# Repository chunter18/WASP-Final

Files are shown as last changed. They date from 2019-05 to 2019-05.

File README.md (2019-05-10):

# WASP

This is the final code submission of my senior design project for Santa Clara University School of Engineering. 

Team memebers:
Tyler Hack
Cole Hunter
Daniel Webber

Advisers:
Dr. Wilson
Dr. Dezfouli

## What is WASP?

WASP (Wireless Analog Sensor Platform) is my teams senior deisng project, the goal of which is to create a simple, powerful, accurate, and compact way to measure accleration for sattelite tests. Here are some snippets from our abstract:

WASP’s goal is to augment and eventually replace the bulky, costly, and inefficient data acquisition systems used for vibrational reliability tests on satellites. This will enable precise testing of conditions on a smaller time frame and at a lower cost.

The project objective is to design a low power, small footprint, wireless sensor module designed to be the next generation in space flight operational testing. Currently, Space and Aerospace companies conduct non-destructive vibrational experiments on their vehicles to ensure that they will survive the high G-forces required to leave the atmosphere. These tests are conducted with over 200 wired accelerometers simultaneously connected to multi-thousand dollar data acquisition modules. These systems result in a disarray of wired connections making installing and debugging these sensors an excessively laborious and time-consuming process. We propose a low-cost, battery-powered module, designed for engineers, to augment and eventually replace the current testing and data acquisition system. The goal is to maintain the accuracy and precision of the current standard of testing, but eliminate the pitfalls of a wired system. These experiments typically last for tens of minutes and up to an hour each time, during which the module will be collecting vibrational data at a very high speed and streaming this data continuously to a base station for analysis. The module must be ultra-low-powered as sensor placement in hard to access locations can occur weeks before the actual experiment takes place. The module will need to be small enough so as not to contribute to system load, which can skew measurements. The final system needs to function in parity with the current system.

As of June 2019, we submitted our final design for a board (including 5 assembled and evaluated boards funded by our project sponsor - Analog Devices) as well as all of the code for the main application we wrote.

In this repository you will find our teams final platform code, the board files, instructions for evaluating one of the rev1 WASP modules, and anything else we want to deliver as a part of the project. To see some more (messy) test code, you can have a look at my other WASP repo, where you can see the expiriments we ran throughout the year.  

## Evaluation Instuctions

For these instructions, we will assume you are famiair with the WICED (Wireless Internet Connectivity for Embedded Devices) software. If you arent, please head over to https://www.cypress.com/products/wiced-software and download WICED studio. We are using version 6.2 for all of our WASP builds, but any version ^ or greater should work.

To start, clone this repository and place it into your WICED studio directory. On windows, the default directory is Documents\WICED-Studio-6.2\43xxx_Wi-Fi\apps. 

Next, we need to modify a few of the base WICED files.
1. First we need to modify wwd_wifi. WASP adds a function to dissasociate with the wifi network to make changing the netowork dynamically easy - the file is otherwise unchanged, so replacing the files wont break any other builds. To do this, replace the wwd_wifi.c in WICED-Studio-6.2\43xxx_Wi-Fi\WICED\WWD\internal\ with the file in the cloned wwd folder, and replace the wwd_wifi.h file in WICED-Studio-6.2\43xxx_Wi-Fi\WICED\WWD\include\ folder.
2. Navigate to https://community.cypress.com/docs/DOC-16139 and follow the steps in the attached document to add the quicksilver platform to the OTA2 libraries. NOTE: it is not necessary to edit the Quicksilver platform.c/.h files for our use case. Hopefully in future versions of WICED these changes will be merged into WICED, so if you notice thats the case you can safely ignore this step. 
3. We will also need to modiy the SPI bitbang code to support MOSI idle high for the ADX4008 ADC. Replace 43xxx_Wi-Fi\WICED\platform\MCU\BCM4390x\peripherals\platform_spi_i2c.c with the one from the repo. 
4. For the final edit, we will need to edit the OpenOCD file for the CYW so that we can use the SEGGER J-link as our JTAG programmer. Replace BCM4390x.cfg with the one from this repo in 43xxx_Wi-Fi\tools\OpenOCD. 

To use the SEGGER J-link as your JTAG programmer, you will also need to follow the instructions at https://community.cypress.com/community/wiced-wifi/wiced-wifi-forums/blog/2018/03/19/downloading-and-debugging-cyw43907-using-jlink-segger. NOTE: this link does not include any instructions to install the j-link drivers - please do this as well.

Next, we need to build the OTA2 extract application that WASPs OTA system relies on. To do so, simple place this make target into your makefiles pane `snip.ota2_extract-Quicksilver_EVL` and double click to build it. This app doesnt need to be downloaded, but it is a prerequsite to building the main app.

Our final step before building is to change some of the WASP defualts to better match your test case.
1. Change the battery capacity in headers/WASP_i2c.h to match your battery of choice. Many popular battery sizes are included, so you may just comment out all but the correct one. NOTE: WASP expects a single celled LiPo battery.
2. Change the server IP address to match you own in headers/wasp_network_global.h
3. Change the wifi networking in wifi_config_dct.c to match your own.

You are no finally ready to build the WASP app! To do so, place the following make target into your list `WASP.wasp_main-Quicksilver_EVL JTAG=jlink ota2_image download_apps download run` and run it. This will build and download the app onto the WASP board for evaluation.

IMPORTANT!!! The wasp server uses the clients MAC address to correlate which data came from which board. By default, WICE will build all the board images with the same mac adress - you will need to change the mac for each board you upload to by editing the `generated_mac_address.txt` file.

To see what the platform is running, connect any UART to USB device to the WASP board UART headers, and open the associated com port. the WASP app prints some various information to the console, which can be useful for debugging.

In addition to this, the WASP server will need to be running in order to see the full functionality of the test app (otherwise the board will stop after failing to connect over TCP). To build the server, cd into the server directory of the repo and run make. The server will then be ready to run 

troubleshooting
1. Check that the OTA extract was built successfully
2. Check that the built server IP matches the actual IP of the server on the local network. 
3. Did the OTA failsafe accidently get set?
3. Feel free to contact me for any other issues you may face. 

## Server

To run the server, first build the file using the included makefile, and run the generated file `wasp`. Note: the wasp server relies on many of the libraries provided by the linux kernel, so make sure the file is built on a semi-recent linux machine.

When the server starts, you should see it immidetly start printing out some basic information, like the servers current mode, the number of reciever threads running, and a table of connected boards which will initially be empty. 

Fundamentally, the server has three different modes: Hibernate (0), Initializing Test Sequence (1), and Test Active (2). The mode is set by a file which will be generated for you by the server. The default mode is hibernate, which will send any connected boards back to hibernate. Each board that connects will have its mac address displayed on the table, as well as its self test status and the time since its last registration with the server.

ONce you have turned on your boards and have seen thier connections on the table, you can begin to test 

## Evaluating the OTA functionality

To use the OTA function of the WASP board, you will need to follow a few additional steps.

1. First, you will need to build your new application to be loaded. To do so, simply add ota2_image to your makefile while removing any of the download commands like so: `WASP.wasp_main-Quicksilver_EVL ota2_image`. This will build the the file `OTA2_image_file.bin` in the build/WASP.wasp_main-Quicksilver_EVL/ directory. This file includes all of the pieces necessary for the full app in a single file (bootloader, filesystem, apps code, dct, etc)
2. Place the included mongoose HTTP server and OTA image file together in the same directory on the server and run the mongoose server.
3. Make sure the OTA flag is set by the TCP portion of the server - TODO
4. Watch it update! you may wish to connect to the WASP board via UART to watch the download progress. The log level has been set to it max allowed level so the UART will be printing a lot of data. You should see the download complete, the board restart, extract the new file, and finllay run the newly updated application.

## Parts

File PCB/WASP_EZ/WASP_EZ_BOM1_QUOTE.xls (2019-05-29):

This is a sample BOM for Sierra Circuits' online BOM pricing system. Please use this preferred format for your BOM that you upload.
Note: DNI applies to whole row. If only some specific locations of a given ITEM are not to be installed, please create two rows for that item and mark one as DNI.
BOM: WASPEZ_1
Assembly Part Number/Revision: 1
Customer / Company Name: Daniel Webber
Item # | Quantity per board | Manufacturer Part # | Do Not Install | Reference designators | Vendor (optional) | Vendor Part Number (optional) | Value (optional) | Size / Footprint (optional) | Part description/ specs (optional, but recommended) | Manfacturer (optional)
1 | 1 | TPS63020DSJR |  | U1 | Mouser | 595-TPS63020DSJR |  | VSON-14 | Switching Voltage Regulators 93% Eff Buck-Boost Converter | TI
2 | 1 | LTC2941CDCB-1#TRMPBF |  | U2 | Mouser | LTC2941CDCB-1#TRMPBF |  | DFN-6 | Battery Management 1A I2C Bat Gas Gauge w/ Int Sense Res | Analog Devices
3 | 2 | CRCW040210R0JNEDC |  | R15, R17 | Mouser | 71-CRCW040210R0JNEDC | 10 ohms | R0402 | 10R 5% 0402 (1005 Metric) SMD | Vishay
4 | 2 | CRCW040220K0JNED |  | R6, R45 | Mouser | 71-CRCW0402J-20K-E3 | 20k ohms | R0402 | 20K 5% 0402 (1005 Metric) SMD | Vishay
5 | 2 | RC0402JR-0733KL |  | R21, R22 | Mouser | 603-RC0402JR-0733KL | 33k ohms | R0402 | 33K 5% 0402(1005) | Yageo
6 | 4 | RC0402JR-0747KL |  | R3, R4, R12, R13 | Mouser | 603-RC0402JR-0747KL | 47k ohms | R0402 | 47K 5% 0402(1005) | Yageo
7 | 6 | RC0402JR-13100KL |  | R5, R10, R11, R16, R24, R26 | Mouser | 603-RC0402JR-13100KL | 100k ohms | R0402 | 100K 5% 0402(1005) | Yageo
8 | 2 | RT0402FRE07130RL |  | R23, R25 | Mouser | 603-RT0402FRE07130RL | 130 ohms | R0402 | 130R 0.063W 5% 0402 (1005 Metric) SMD | Yageo
9 | 1 | RC0402FR-07143KL |  | R2 | Mouser | 603-RC0402FR-07143KL | 143k ohms | R0402 | 143K 1% 0402(1005) | Yageo
10 | 1 | RC0402FR-07715RL |  | R9 | Mouser | 603-RC0402FR-07715RL | 715 ohms | R0402 | 715R 0.063W 1% 0402 (1005 Metric) SMD | Yageo
11 | 1 | RC0402FR-07910KL |  | R1 | Mouser | 603-RC0402FR-07910KL | 910k ohm | R0402 | 910K 0.063W 1% 0402 (1005 Metric) SMD | Yageo
12 | 1 | AD4008BCPZ-RL7 |  | U6 | Mouser | 584-AD4008BCPZ-RL7 |  | LFCSP-10 | Analog to Digital Converters - ADC 16-Bit, 500 KSPS PulSAR ADC | Analog Devices
13 | 1 | ADXL1004BCPZ |  | U4 | Mouser | 584-ADXL1004BCPZ |  | LFCSP-32 | Accelerometers Low Noise 50kHz 500g 1-axis accel | Analog Devices
14 | 7 | CRCW04020000Z0EDC |  | R7, R8, R18, R19, R28, R35, R38 | Mouser | 71-CRCW04020000Z0EDC | 0 ohm | R0402 | Jumper 0402 (1005 Metric) | Yageo
15 | 1 | APG1608CGKC/T |  | DS1 | Mouser | 604-APG1608CGKC/T |  | LED 0603 | LED, SMT, 0603(1608), 0.25mm Thickness, Green | Kingbright
16 | 1 | S2B-PH-K-S(LF)(SN) |  | P2 | Digikey | 455-1719-ND |  |  | Male Header, Pitch 2 mm, 1 x 2 Position, Height 4.8 mm, Tail Length 3.4 mm, | JST Sales America Inc.
17 | 1 | LT1461CIS8-3.3#PBF |  | U5 | Digikey | LT1461CIS8-3.3#PBF-ND |  | 8-SOIC | Series Voltage Reference IC ±0.08% 100mA 8-SOIC | Analog Devices
18 | 1 | QUICKSILVER |  | M1 | Arrow | QUICKSILVER |  |  | Module, Antenna, .05 pitch, https://www.arrow.com/en/products/quicksilver/arrow-development-tools | Arrow
19 | 2 | RCWE0603R220FKEA |  | R14, R20 | Mouser | 71-RCWE0603R220FKEA | .22 ohm | R0603 | Current Sense Resistors - SMD 1/5watt .22ohms 1% 100ppm | Vishay
20 | 1 | XFL4020-102MEC |  | L1 | Mouser | 994-XFL4020-102MEC |  |  | Shielded Power Inductor, 1 uH, 64 MHz | Coilcraft
21 | 1 | TPS73733DCQR |  | U3 | Mouser | 595-TPS73733DCQR | 3.3V LDO | SOT-223 | LDO Voltage Regulators Cap-Free 1A LDO Reg | TI
22 | 1 | TPS780180300DRVR |  | U9 | Mouser | 595-TPS780180300DRVR | 1.8V LDO | WSON-6 | Single Output LDO, 150 mA, Fixed 1.8, 3.0 V Output, 2.2 to 5.5 V Input, | TI
23 | 1 | SIS407ADN-T1-GE3 |  | Q1 | Mouser | 78-SIS407ADN-T1-GE3 |  | PowerPAK 1212-8 | MOSFET -20V Vds 8V Vgs PowerPAK 1212-8 | Vishay
24 | 1 | NTUD3170NZT5G |  | Q2 | Mouser | 863-NTUD3170NZT5G |  | SOT-963-6 | Small Signal MOSFET, 20 V, 220 mA, Dual N-Channel, 6-Pin SOT-963, Pb-Free, Tape and Reel | ON Semiconductor
25 | 2 | 5012 |  | TP3, TP13 | Mouser | 534-5012 |  |  | Circuit Board Hardware - PCB WHITE TEST POINT | Keystone
26 | 1 | APG1608SURKC/T |  | DS2 | Mouser | 604-APG1608SURKC/T | RED LED | LED 0603 | Standard LEDs - SMD Red, Water Clear 320mcd, 631nm | Kingbright
27 | 2 | B3U-1000P |  | SW1, SW2 | Mouser | 653-B3U-1000P |  |  | Tactile Switches Top Actuated w/o boss w/o ground | Omron
28 | 1 | INA219BIDCNT |  | U7 | Digikey | 296-27898-2-ND |  | SOT-23-8 | Current Monitor Regulator High-Side 10mA SOT-23-8 | TI
29 | 4 | 77311-801-04LF |  | P1, P3, P4, P5 | Digikey | 649-77311-801-04LF |  |  | Headers & Wire Housings Unshrd Hdr, Sngl Rw Thru-Mount,4P,Strght | Amphenol FCI
30 | 2 | EMK105BJ105KV-F |  | C14, C31 | Digikey | 587-2477-1-ND | 1uF | C0402 | CAP CER 1UF 16V X5R 0402 | Taiyo Yuden
31 | 3 | CC0402KPX5R6BB225 |  | C36, C37, C22 | Mouser | 603-CC0402KPX56BB225 | 2.2uF | C0402 | Multilayer Ceramic Capacitors MLCC - SMD/SMT 2.2uF 10% 10V | Yageo
32 | 12 | GRM188R61A106KE69D |  | C1, C2, C5, C6, C7, C8, C9, C16, C19, C20, C21,C10 | Digikey | 490-10474-1-ND | 10uF | C0603 | CAP CER 10UF 10V X5R 0603 | Murata
33 | 8 | CGA2B2X5R1A104K050BA |  | C3, C15, C17, C18, C28, C29, C35, C4 | Digikey | 445-12156-1-ND | 0.1uF | C0402 | CAP CER 0.1UF 10V X5R 0402 | TDK
34 | 4 | CC0603KRX5R9BB104 |  | C11, C23, C26, C27 | Digikey | 311-4046-1-ND | 0.1uF | C0603 | CAP CER 0.1UF 50V X5R 0603 | Yageo
35 | 2 | GRM155R71C104KA88J |  | C24, C25 | Digikey | 490-6328-1-ND | 0.1uF | C0402 | CAP CER 0.1UF 16V X7R 0402 | Murata
36 | 1 | C0603X103F5JAC7867 |  | C12 | Digikey | 399-13405-1-ND | 10000PF | C0603 | CAP CER 10000PF 50V U2J 0603 | KEMET
END OF BOM

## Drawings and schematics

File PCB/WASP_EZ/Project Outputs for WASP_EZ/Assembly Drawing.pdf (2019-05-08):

Line # 123456789 | C3, C15, C17, C18, C28, C29, C35 | CAP 100nF 6.3V 0402(1005)

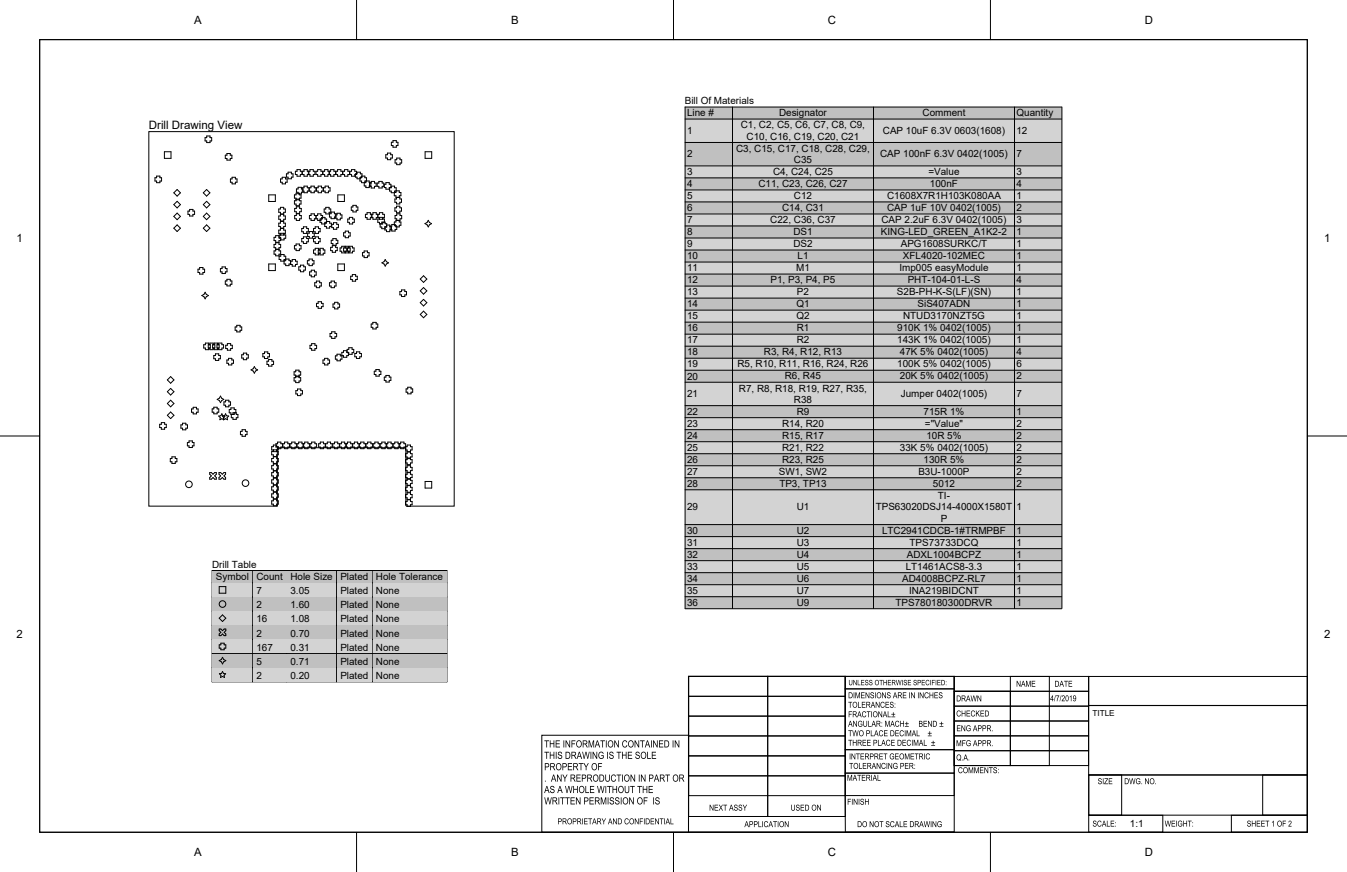
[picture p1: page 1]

Designator | Comment | Quantity

12 | P1, P3, P4, P5 | PHT-104-01-L-S | 1273412311114111114627122222211111111

C1, C2, C5, C6, C7, C8, C9, C10, C16, C19, C20, C21 | CAP 10uF 6.3V 0603(1608)

C4, C24, C25 | =Value
C11, C23, C26, C27 | 100nF

C12 | C1608X7R1H103K080AA
C14, C31 | CAP 1uF 10V 0402(1005)
C22, C36, C37 | CAP 2.2uF 6.3V 0402(1005)
DS1 | KING-LED_GREEN_A1K2-2
DS2 | APG1608SURKC/T

10 | L1 | XFL4020-102MEC
11 | M1 | Imp005 easyModule

13 | P2 | S2B-PH-K-S(LF)(SN)
14 | Q1 | SiS407ADN
15 | Q2 | NTUD3170NZT5G
16 | R1 | 910K 1% 0402(1005)
17 | R2 | 143K 1% 0402(1005)
18 | R3, R4, R12, R13 | 47K 5% 0402(1005)
19 | R5, R10, R11, R16, R24, R26 | 100K 5% 0402(1005)
20 | R6, R45 | 20K 5% 0402(1005)
21 | R7, R8, R18, R19, R27, R35, R38 | Jumper 0402(1005)

22 | R9 | 715R 1%
23 | R14, R20 | ="Value"
24 | R15, R17 | 10R 5%
25 | R21, R22 | 33K 5% 0402(1005)
26 | R23, R25 | 130R 5%
27 | SW1, SW2 | B3U-1000P
28 | TP3, TP13 | 5012
29 | U1 | TI-TPS63020DSJ14-4000X1580T P

30 | U2 | LTC2941CDCB-1#TRMPBF
31 | U3 | TPS73733DCQ
32 | U4 | ADXL1004BCPZ
33 | U5 | LT1461ACS8-3.3

162 | 1.08 | Plated | None
167 52 | 0.71 | Plated | None

0.70 | Plated | None
0.31 | Plated | None

0.20 | Plated | None

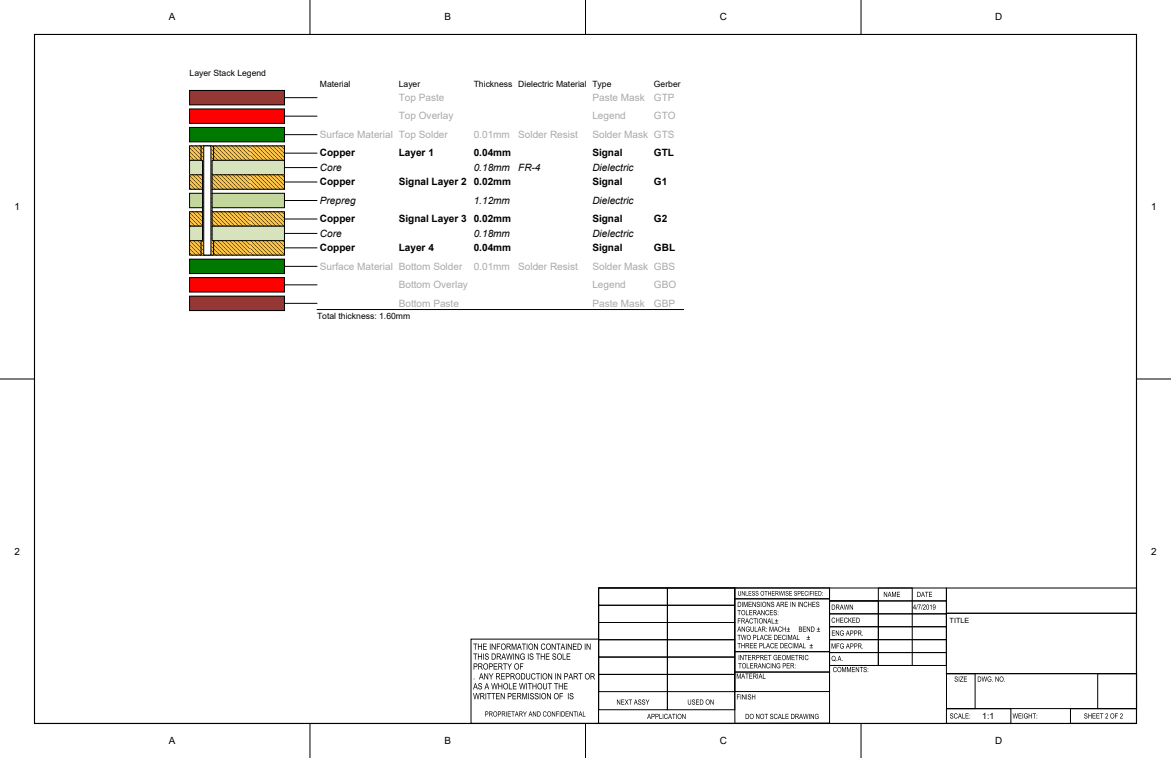
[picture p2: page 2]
Material; Layer; Thickness Dielectric Material Type; Gerber; Top Paste; Paste Mask GTP; Top Overlay; Legend; GTO; Surface Material Top Solder; 0.01mm Solder Resist; Solder Mask GTS; Copper; Layer 1; Signal; GTL; Core; Dielectric; Signal Layer 2 0.02mm; Prepreg; Signal Layer 3 0.02mm; Layer 4; GBL; Surface Material Bottom Solder 0.01mm Solder Resist; Solder Mask GBS; Bottom Overlay; GBO; Bottom Paste; Paste Mask GBP; Total thickness: 1.60mm; TITLE

Layer Stack Legend

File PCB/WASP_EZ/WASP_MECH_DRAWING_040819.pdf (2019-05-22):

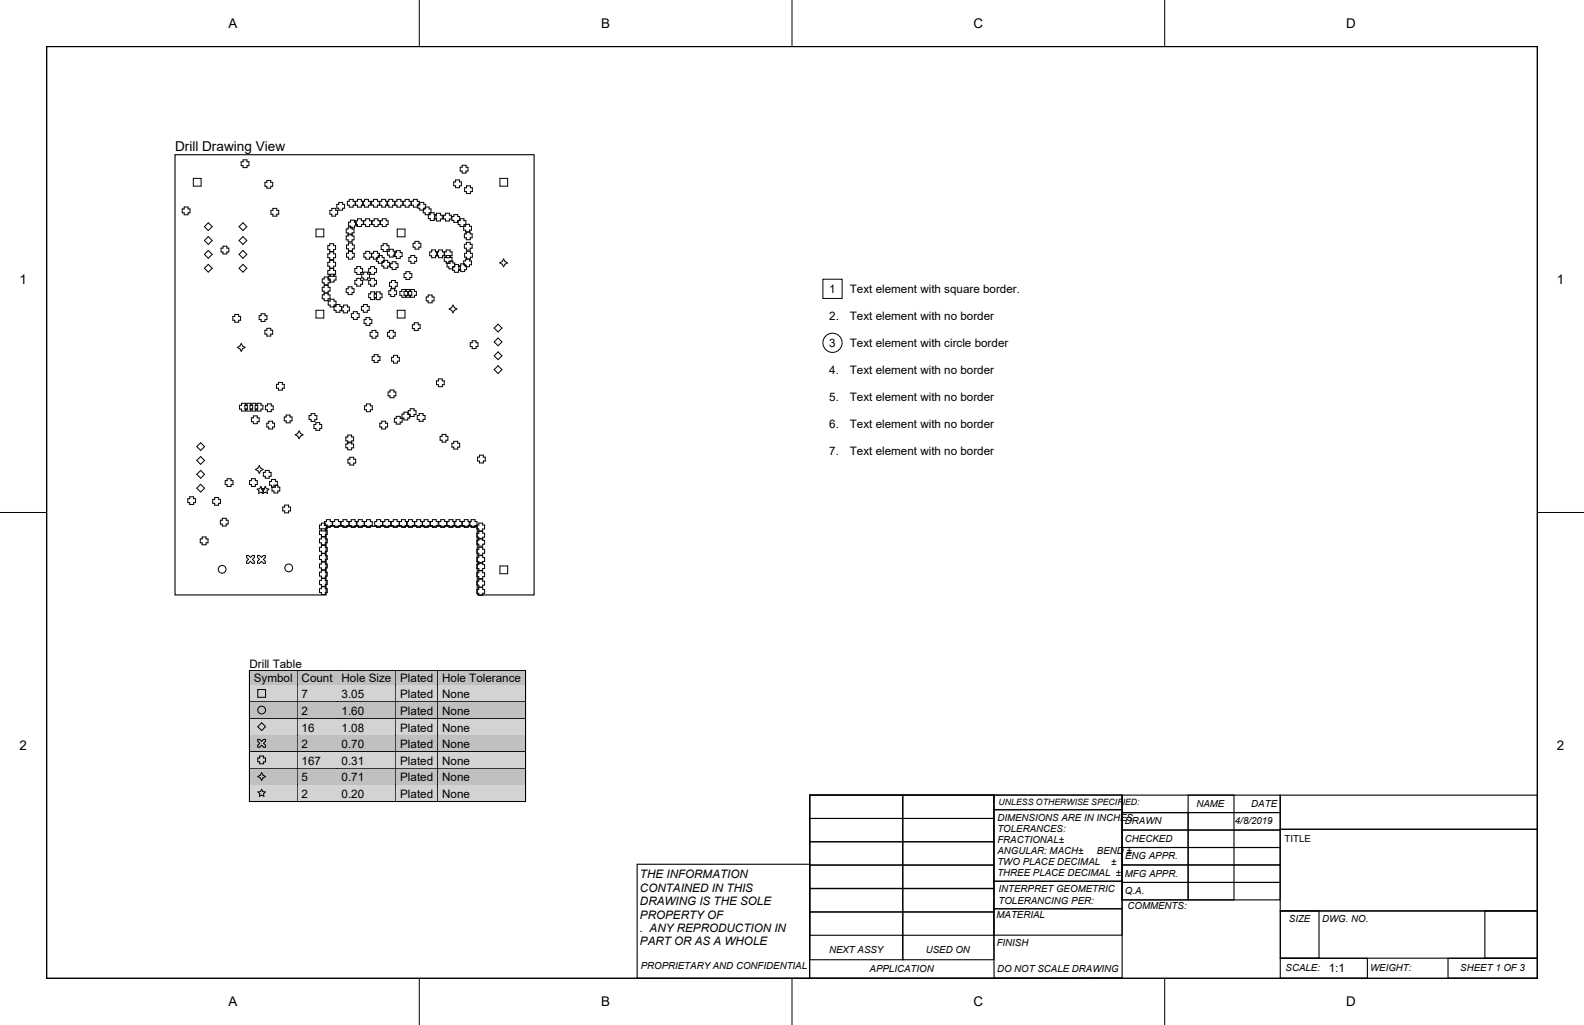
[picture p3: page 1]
Drill Table; DWG. NO.; COMMENTS:; FINISH; APPLICATION; DO NOT SCALE DRAWING; NEXT ASSY; USED ON; ANGULAR: MACH±; BEND ±; NAME; DATE; TITLE; MFG APPR.; ENG APPR.; CHECKED; DRAWN; SCALE:; WEIGHT:; SHEET 1 OF 3; SIZE

Drill Drawing View

1 Text element with square border.

2. Text element with no border

3 Text element with circle border

4. Text element with no border

5. Text element with no border

6. Text element with no border

7. Text element with no border

Symbol | Count | Hole Size | Plated | Hole Tolerance

7 | 3.05 | Plated | None
2 | 1.60 | Plated | None
16 | 1.08 | Plated | None
2 | 0.70 | Plated | None
167 | 0.31 | Plated | None
5 | 0.71 | Plated | None
2 | 0.20 | Plated | None

UNLESS OTHERWISE SPECIFIED:
DIMENSIONS ARE IN INCHES
TOLERANCES:
FRACTIONAL±
TWO PLACE DECIMAL ±
THREE PLACE DECIMAL ±
INTERPRET GEOMETRIC
TOLERANCING PER:
MATERIAL

THE INFORMATION
CONTAINED IN THIS
DRAWING IS THE SOLE
PROPERTY OF
. ANY REPRODUCTION IN
PART OR AS A WHOLE

PROPRIETARY AND CONFIDENTIAL

1 | 1
2 | 2
Material | Layer | Thickness Dielectric Material Type | Gerber
Top Paste | Paste Mask GTP
| Top Overlay | | Legend | GTO
Surface Material Top Solder | 0.01mm Solder Resist | Solder Mask GTS
Copper | Layer 1 | 0.04mm | Signal | GTL
Core | | 0.18mm FR-4 | Dielectric
Copper | Signal Layer 2 | 0.02mm | Signal | G1
Prepreg | | 1.12mm | Dielectric
Copper | Signal Layer 3 | 0.02mm | Signal | G2
Core | | 0.18mm | Dielectric
Copper | Layer 4 | 0.04mm | Signal | GBL
Surface Material Bottom Solder 0.01mm Solder Resist | Solder Mask GBS
| Bottom Overlay | | Legend | GBO
Bottom Paste | Paste Mask GBP
Total thickness: 1.60mm

Layer Stack Legend

DWG. NO.

4/8/2019

COMMENTS:
MATERIAL

UNLESS OTHERWISE SPECIFIED:

INTERPRET GEOMETRIC
TOLERANCING PER:

DIMENSIONS ARE IN INCHES
TOLERANCES:
FRACTIONAL±
ANGULAR: MACH± BEND ±
TWO PLACE DECIMAL ±
THREE PLACE DECIMAL ±

NAME DATE

TITLE

Q.A.

MFG APPR.

ENG APPR.

CHECKED

DRAWN

THE INFORMATION
CONTAINED IN THIS
DRAWING IS THE SOLE
PROPERTY OF
. ANY REPRODUCTION IN

SIZE

# C26 C27C²³

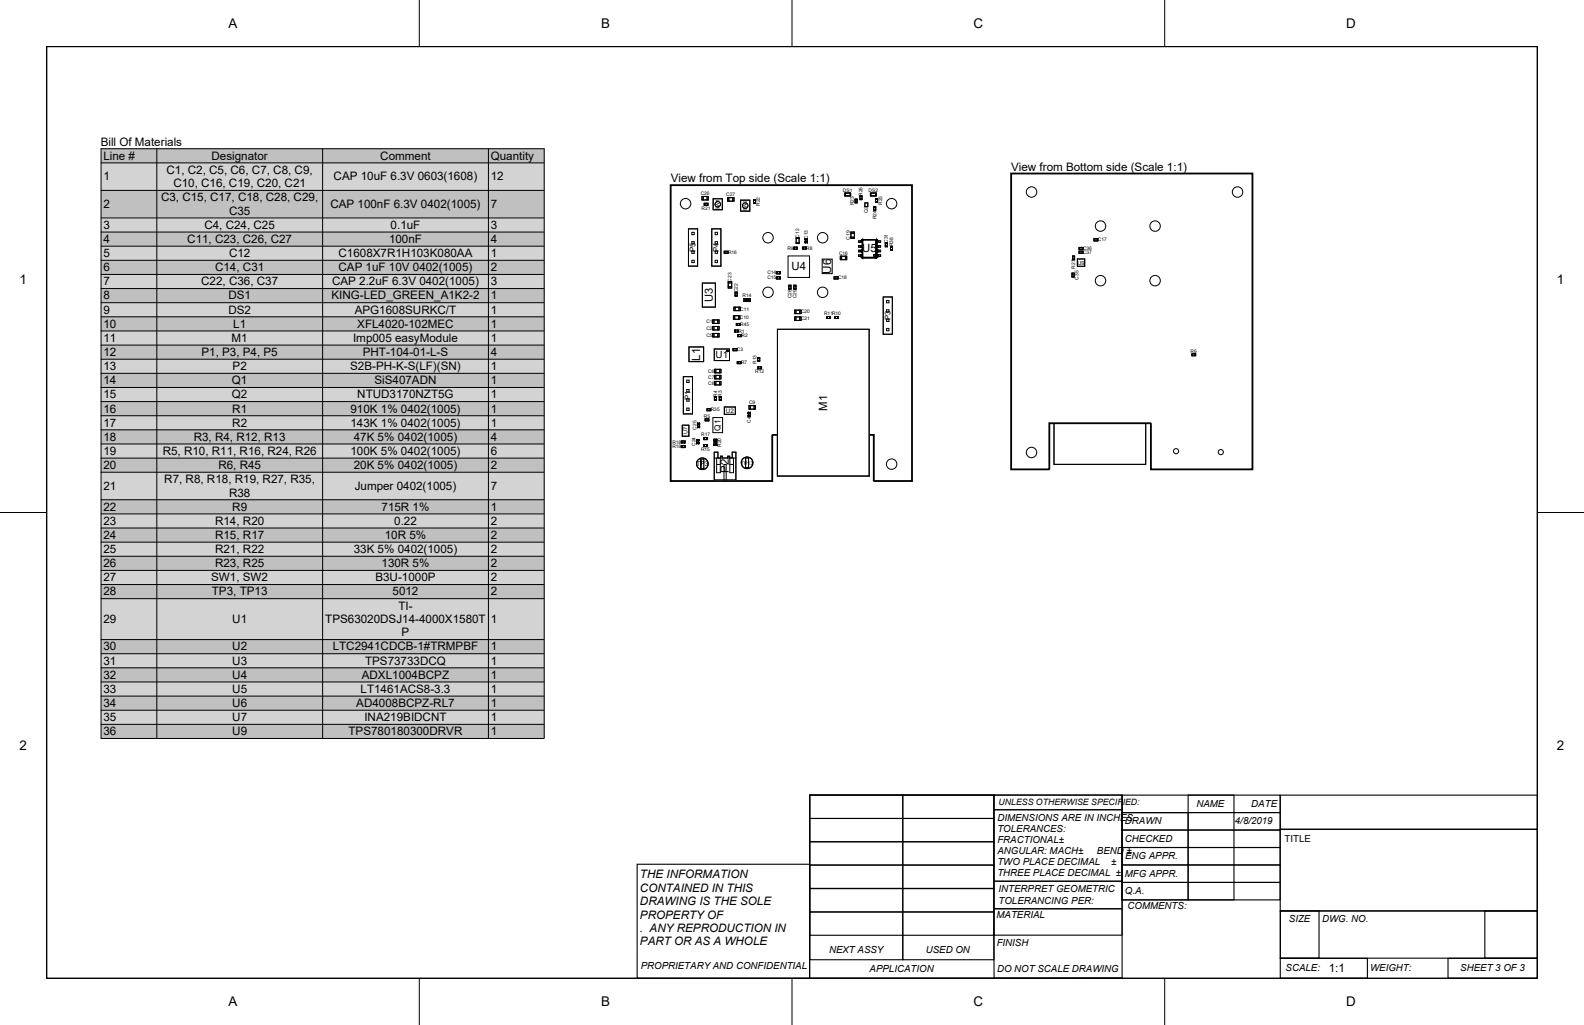
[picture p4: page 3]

Line # | Designator | Comment | Quantity
1 | C1, C2, C5, C6, C7, C8, C9, C10, C16, C19, C20, C21 | CAP 10uF 6.3V 0603(1608) | 12

View from Bottom side (Scale 1:1)

View from Top side (Scale 1:1)

2 | C3, C15, C17, C18, C28, C29, C35 | CAP 100nF 6.3V 0402(1005) | 7

3 | C4, C24, C25 | 0.1uF | 3
4 | C11, C23, C26, C27 | 100nF | 4
5 | C12 | C1608X7R1H103K080AA | 1
6 | C14, C31 | CAP 1uF 10V 0402(1005) | 2
7 | C22, C36, C37 | CAP 2.2uF 6.3V 0402(1005) | 3
8 | DS1 | KING-LED_GREEN_A1K2-2 | 1
9 | DS2 | APG1608SURKC/T | 1
10 | L1 | XFL4020-102MEC | 1
11 | M1 | Imp005 easyModule | 1
12 | P1, P3, P4, P5 | PHT-104-01-L-S | 4
13 | P2 | S2B-PH-K-S(LF)(SN) | 1

14 | Q1 | SiS407ADN | 1
15 | Q2 | NTUD3170NZT5G | 1
16 | R1 | 910K 1% 0402(1005) | 1
17 | R2 | 143K 1% 0402(1005) | 1
18 | R3, R4, R12, R13 | 47K 5% 0402(1005) | 4
19 | R5, R10, R11, R16, R24, R26 | 100K 5% 0402(1005) | 6
20 | R6, R45 | 20K 5% 0402(1005) | 2
21 | R7, R8, R18, R19, R27, R35, R38 | Jumper 0402(1005) | 7

22 | R9 | 715R 1% | 1
23 | R14, R20 | 0.22 | 2
24 | R15, R17 | 10R 5% | 2
25 | R21, R22 | 33K 5% 0402(1005) | 2
26 | R23, R25 | 130R 5% | 2
27 | SW1, SW2 | B3U-1000P | 2
28 | TP3, TP13 | 5012 | 2
29 | U1 | TI-TPS63020DSJ14-4000X1580T P | 1

30 | U2 | LTC2941CDCB-1#TRMPBF | 1
31 | U3 | TPS73733DCQ | 1
32 | U4 | ADXL1004BCPZ | 1
33 | U5 | LT1461ACS8-3.3 | 1
34 | U6 | AD4008BCPZ-RL7 | 1
35 | U7 | INA219BIDCNT | 1
36 | U9 | TPS780180300DRVR | 1

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

THE INFORMATION
CONTAINED IN THIS
DRAWING IS THE SOLE
PROPERTY OF
. ANY REPRODUCTION IN

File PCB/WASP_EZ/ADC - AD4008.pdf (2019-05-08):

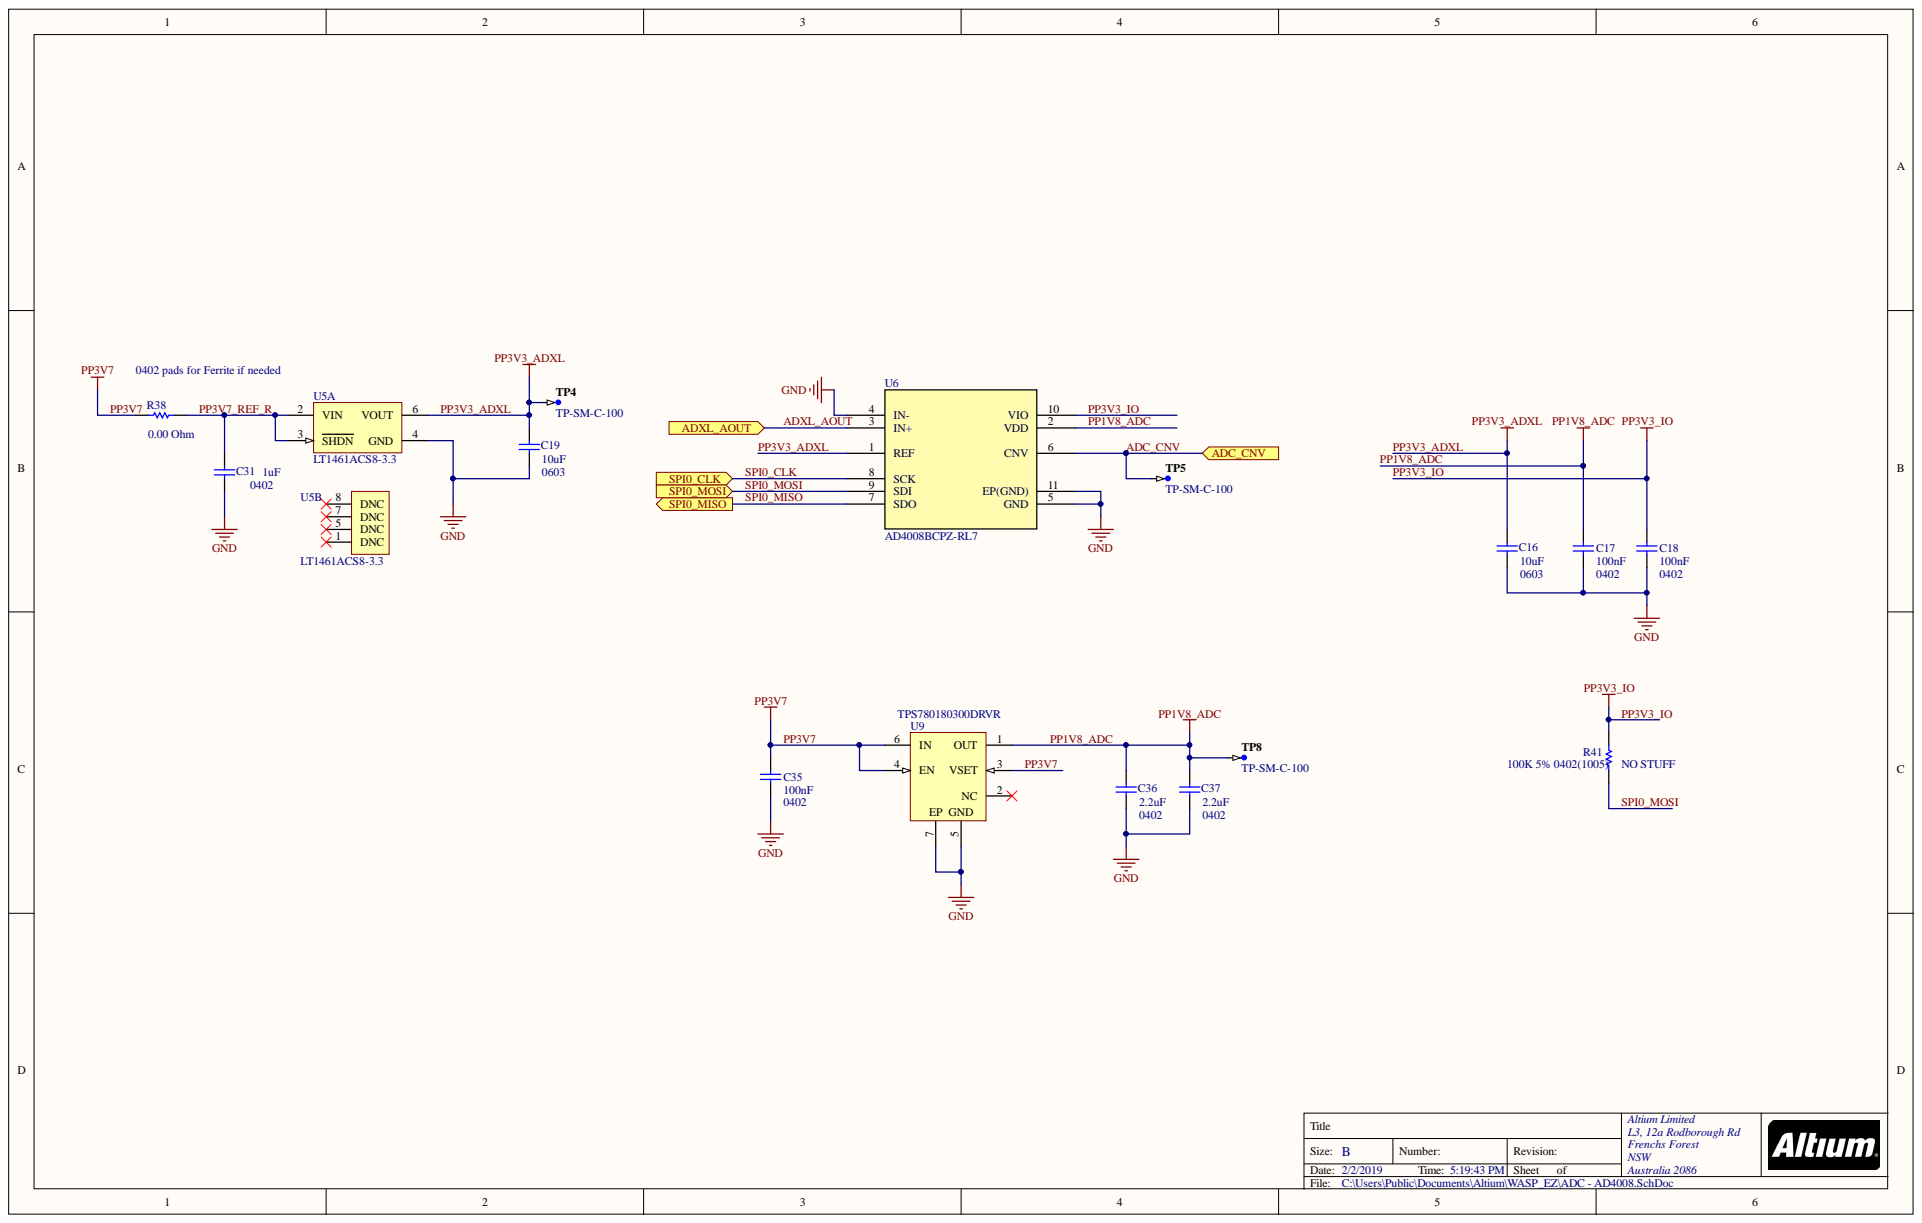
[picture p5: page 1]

0402 pads for Ferrite if needed

Title | Altium Limited L3, 12a Rodborough Rd Frenchs Forest NSW Australia 2086

Size: B | Number: | Revision:
Date: 2/2/2019 Time: 5:19:43 PM | | Sheet of
File: C:\Users\Public\Documents\Altium\WASP_EZ\ADC - AD4008.SchDoc

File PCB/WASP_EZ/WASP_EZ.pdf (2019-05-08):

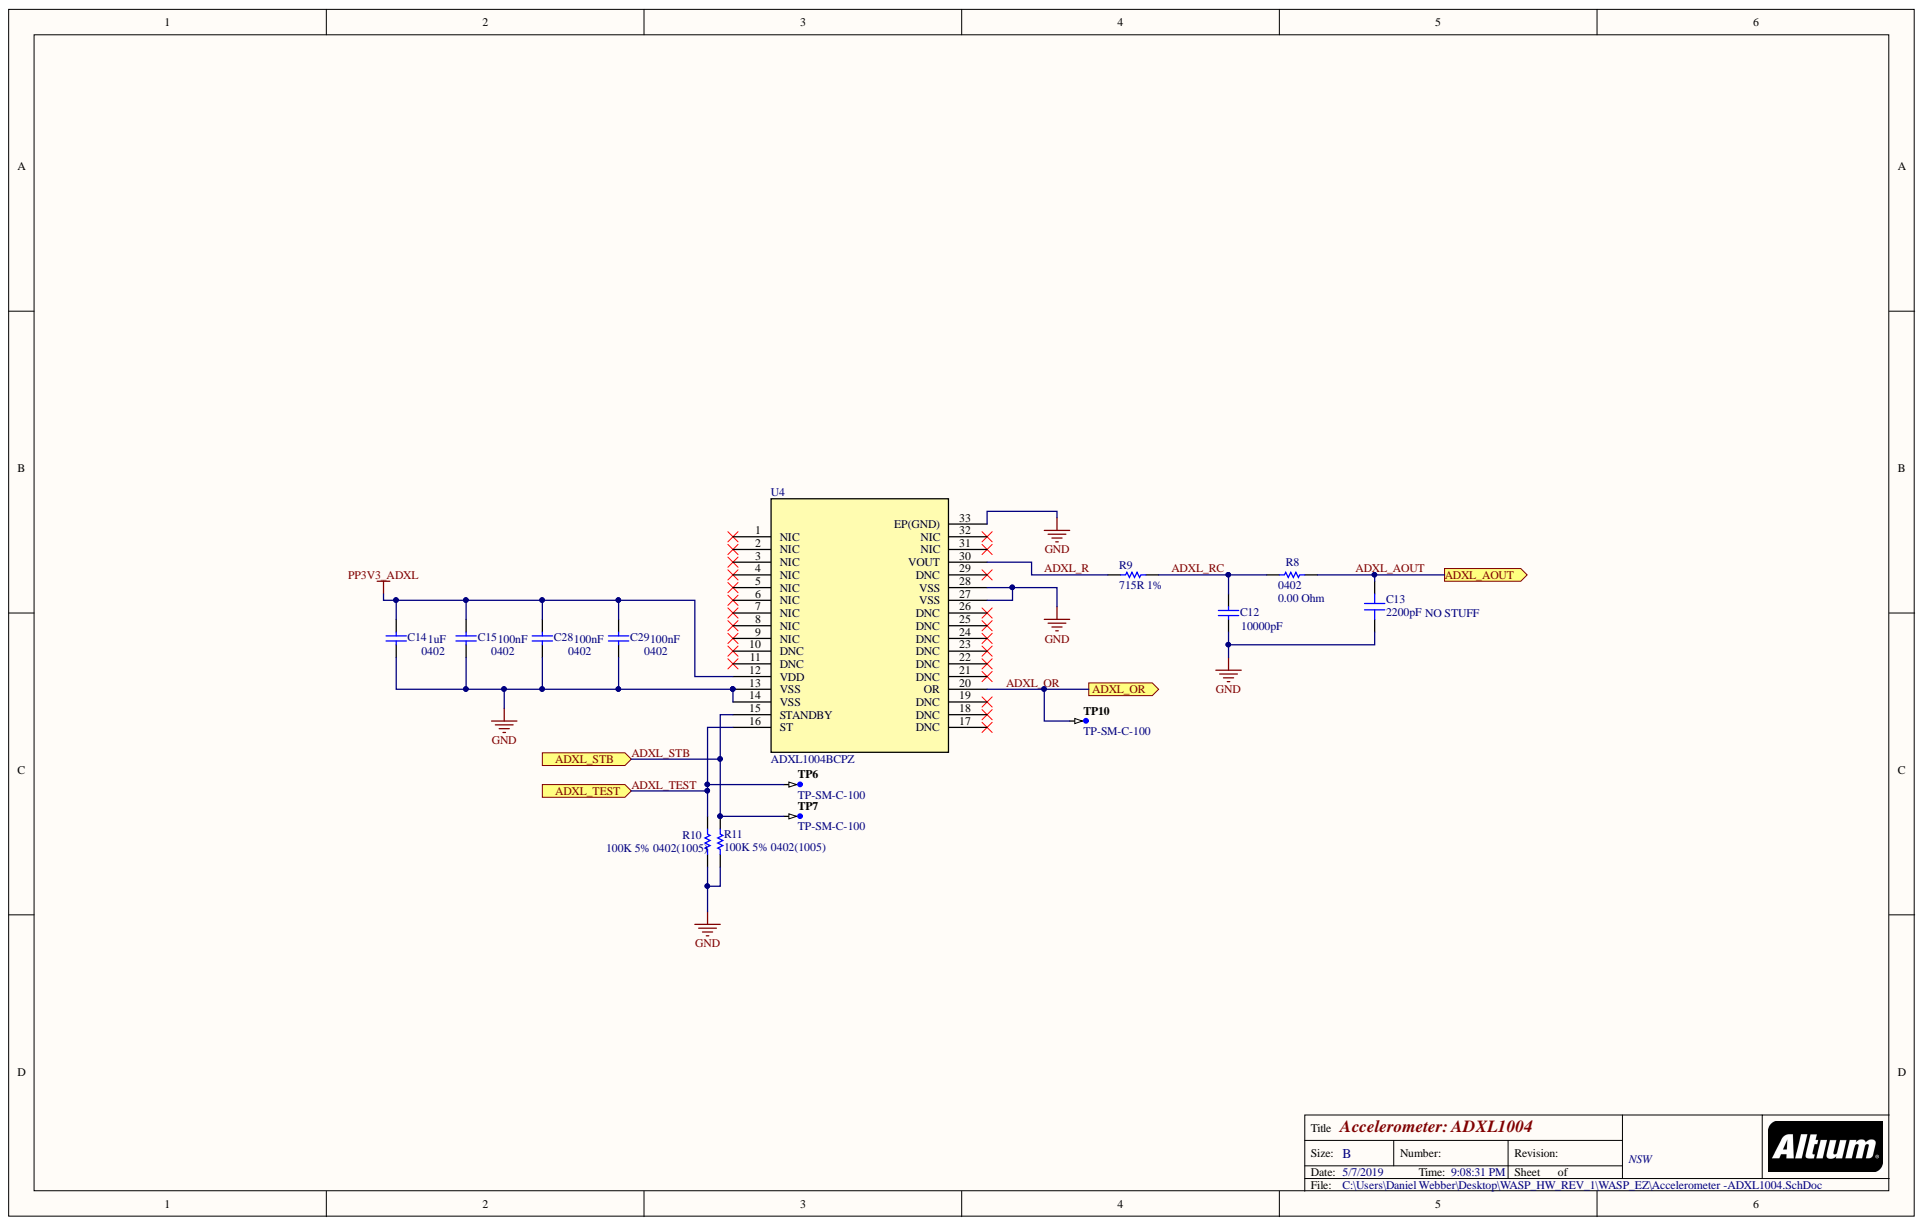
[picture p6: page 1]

Title Accelerometer: ADXL1004 | NSW

Size: B | Number: | Revision:
Date: 5/7/2019 Time: 9:08:31 PM | | Sheet of
File: C:\Users\Daniel Webber\Desktop\WASP_HW_REV_1\WASP_EZ\Accelerometer -ADXL1004.SchDoc

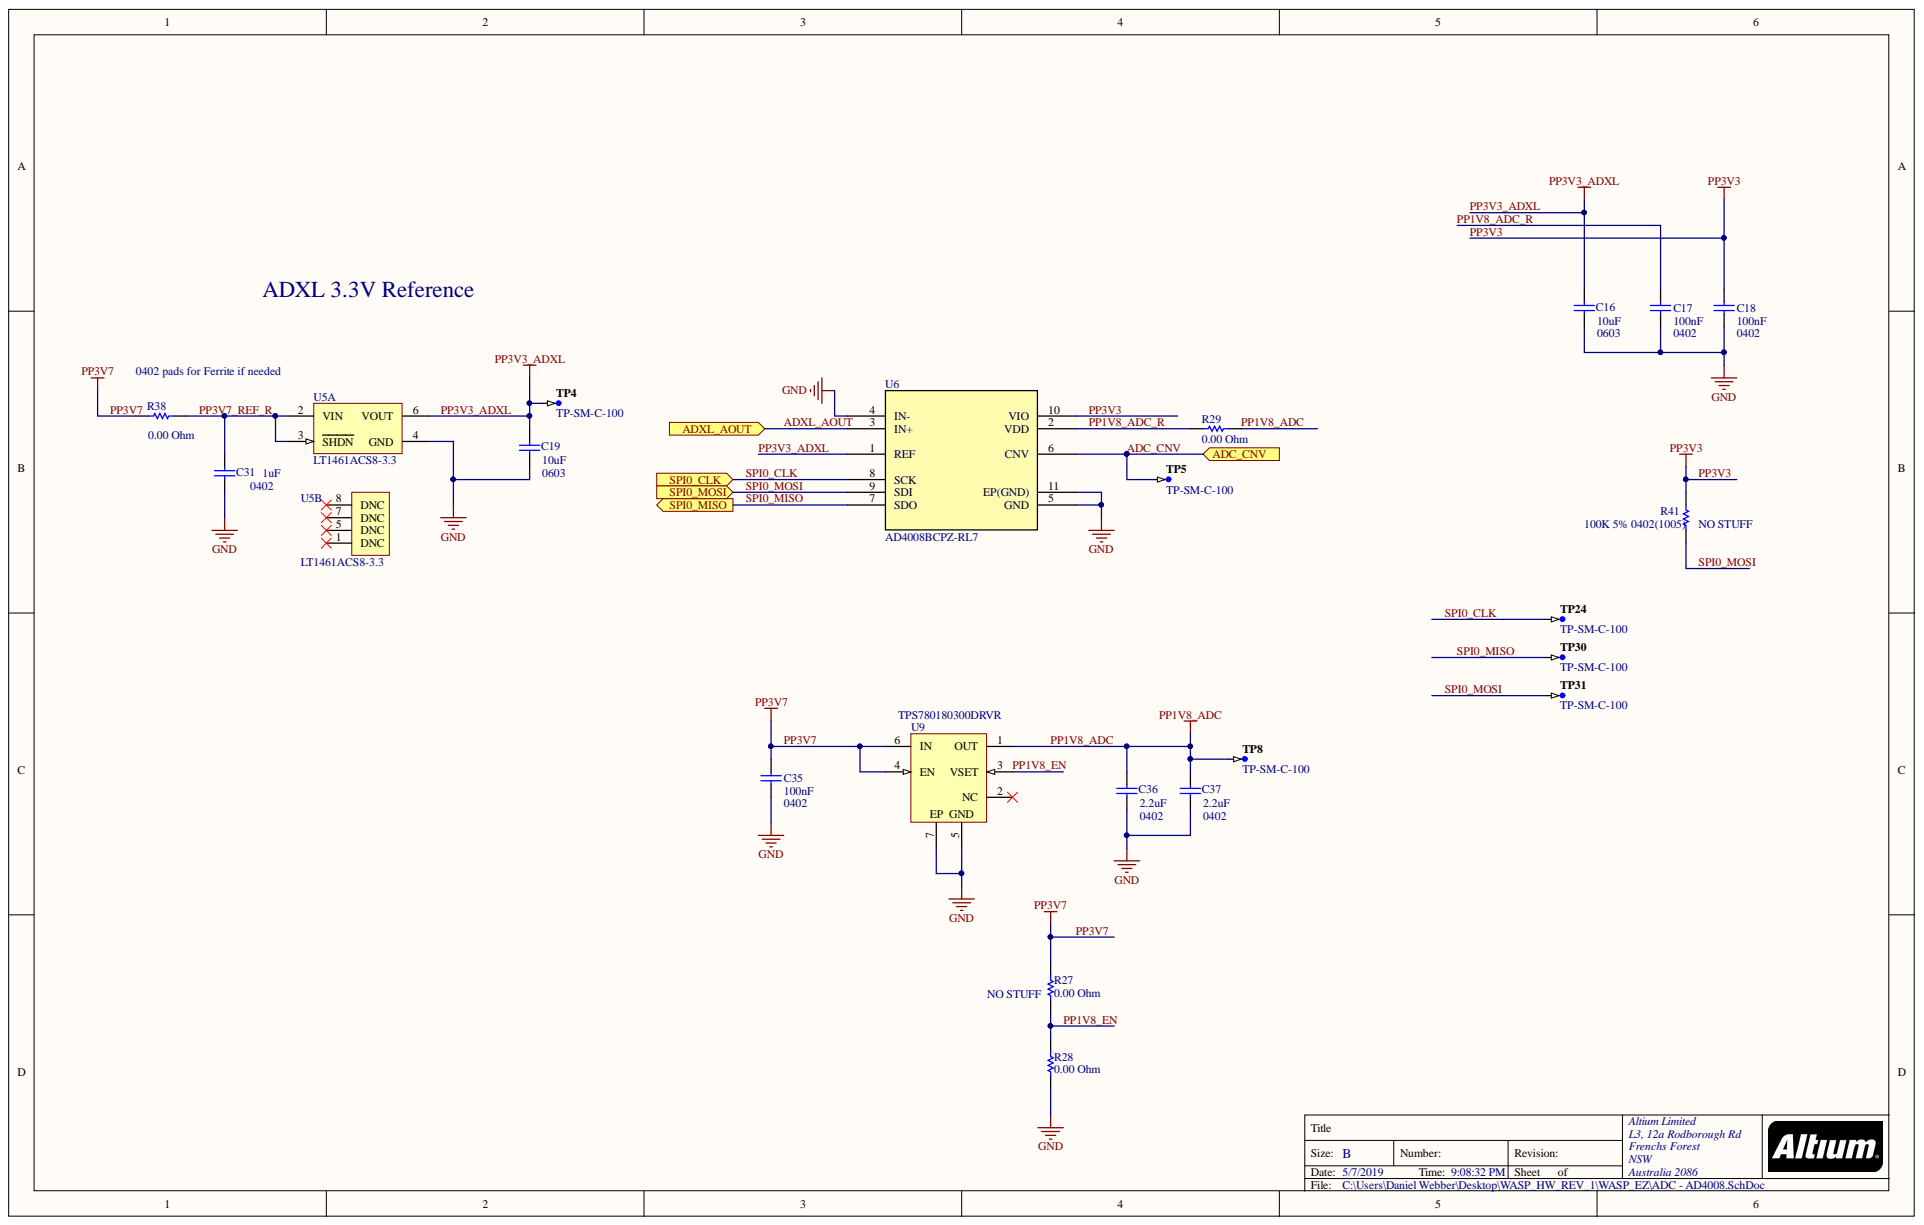
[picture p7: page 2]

0402 pads for Ferrite if needed

Date:
C:\Users\Daniel Webber\Desktop\WASP_HW_REV_1\WASP_EZ\ADC - AD4008.SchDoc

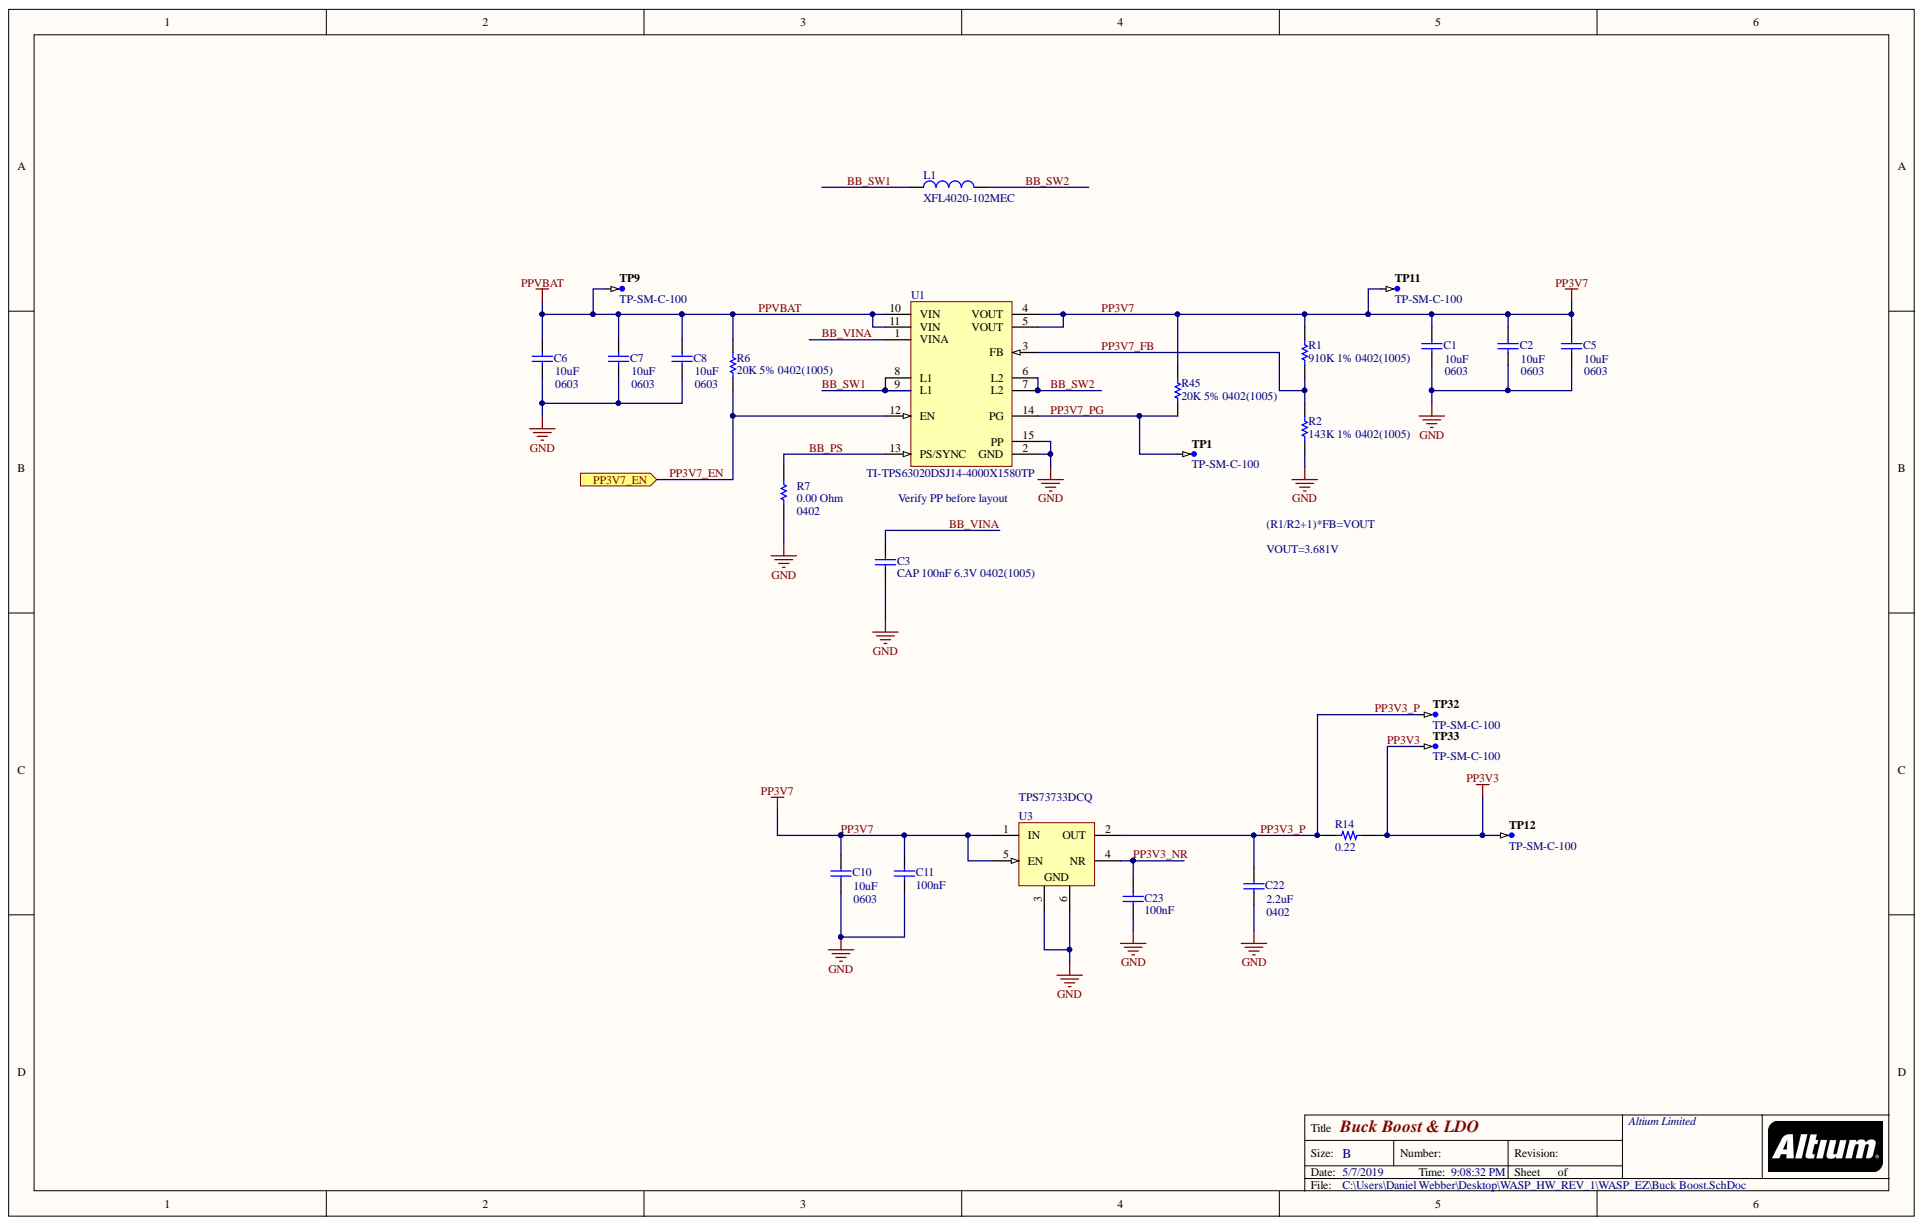
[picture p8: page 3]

VINA 1 | | C2

Verify PP before layout

Title | Altium Limited Buck Boost & LDO

Size: B | Number: | Revision:
Date: 5/7/2019 Time: 9:08:32 PM | | Sheet of
File: C:\Users\Daniel Webber\Desktop\WASP_HW_REV_1\WASP_EZ\Buck Boost.SchDoc

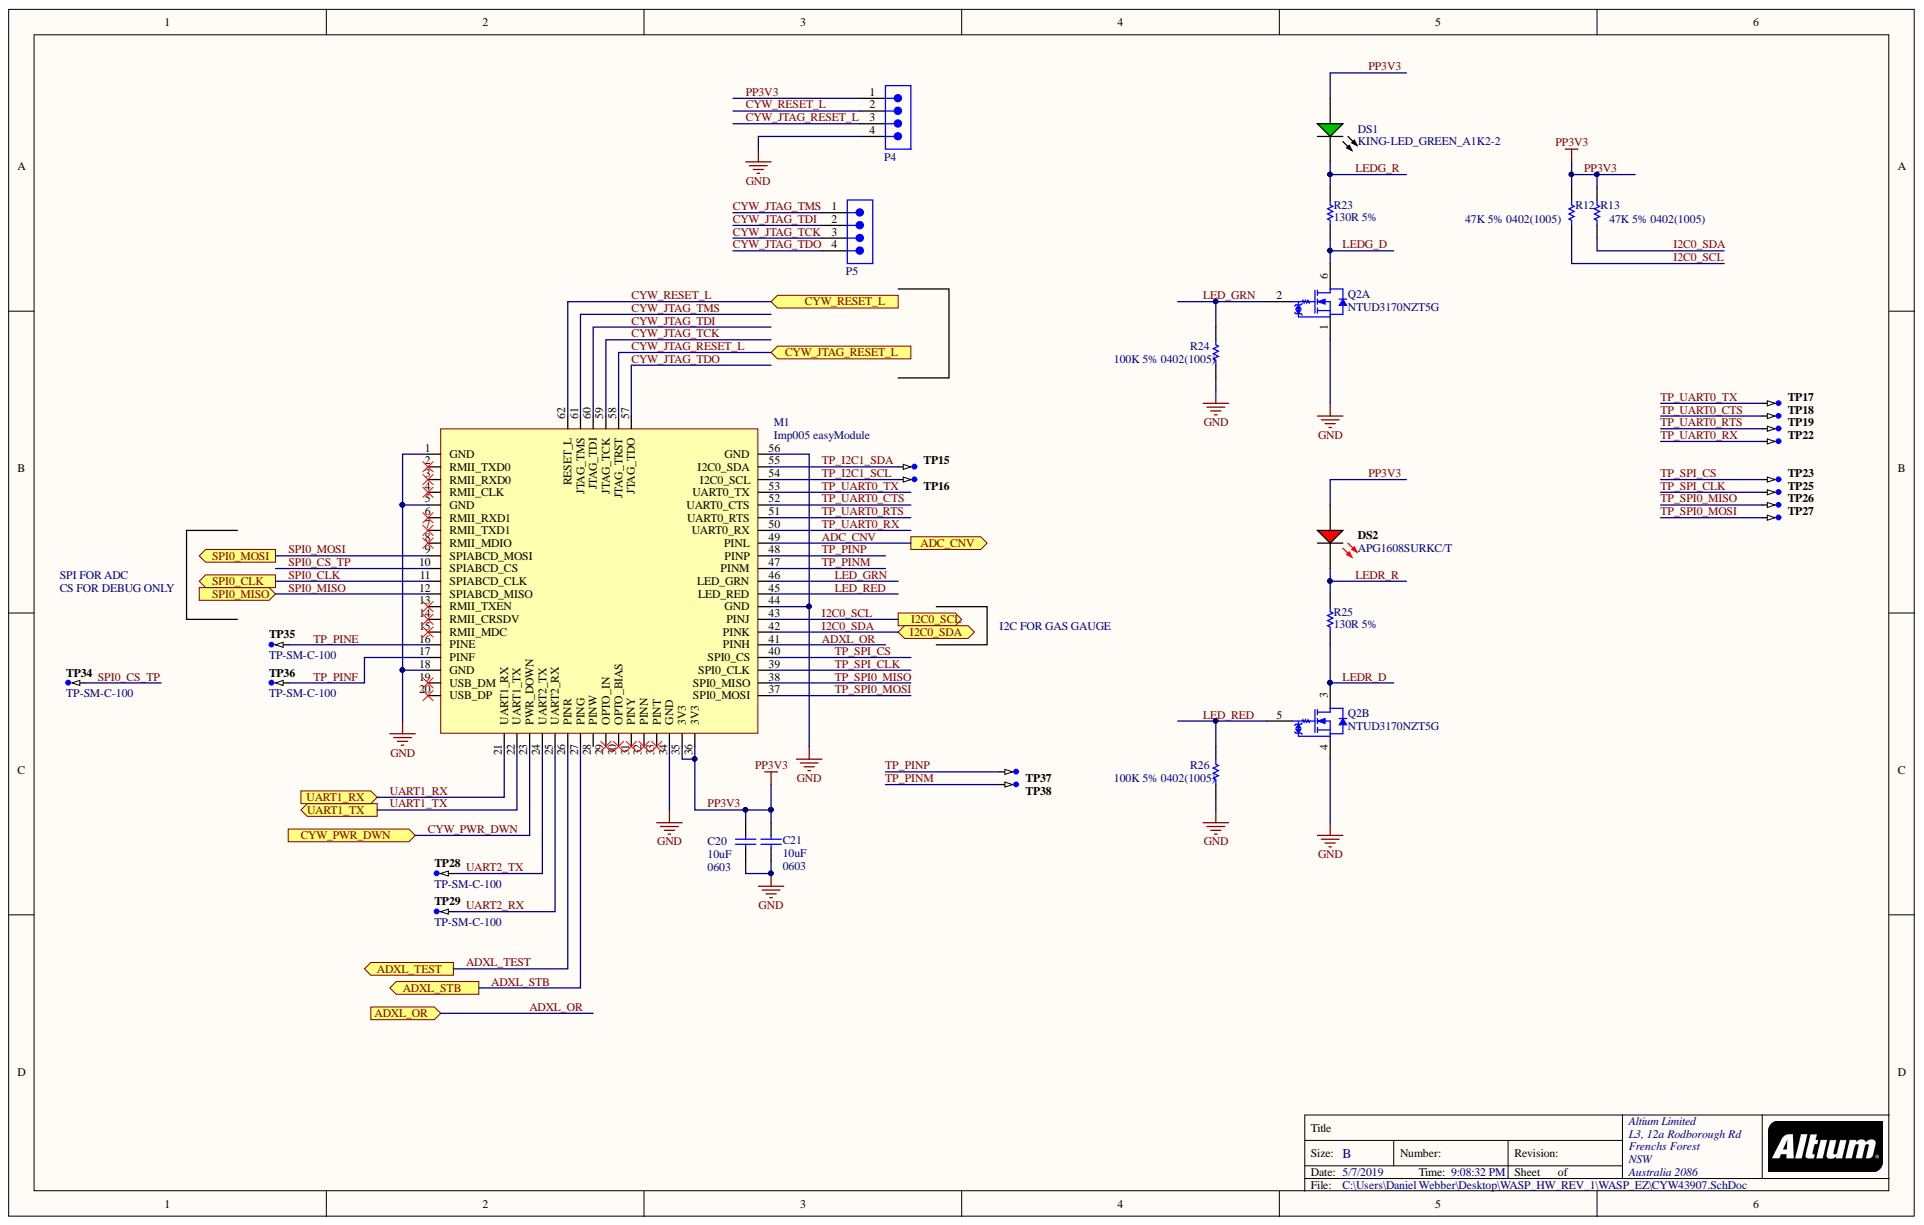
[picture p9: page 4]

3 | | TP_I2C1_SC L
4 | | TP_U A RT0_T X
5 | | TP_U A RT0_C T S
6 1 | | TP_U A RT0_R T S

TP_PI N M
L E D_G R N
L E D_R E D

TP_SPI_C L K
TP_SPI0_M ISO
TP_SPI0_M OSI

Ti tl e | A l t ium Li m i ted L3, 12a Rodborough R d F renchs Fores t NSW Aus tral ia 2086

Size: B | Number : | Revi s ion:
Date: 5/7/2019 Ti me: 9:08:32 PM | | Sheet of
Fi le: C : \U ser s \Daniel Webber \Desktop\WASP_H W_R E V_1\WASP_E Z \ C Y W43907.SchDoc

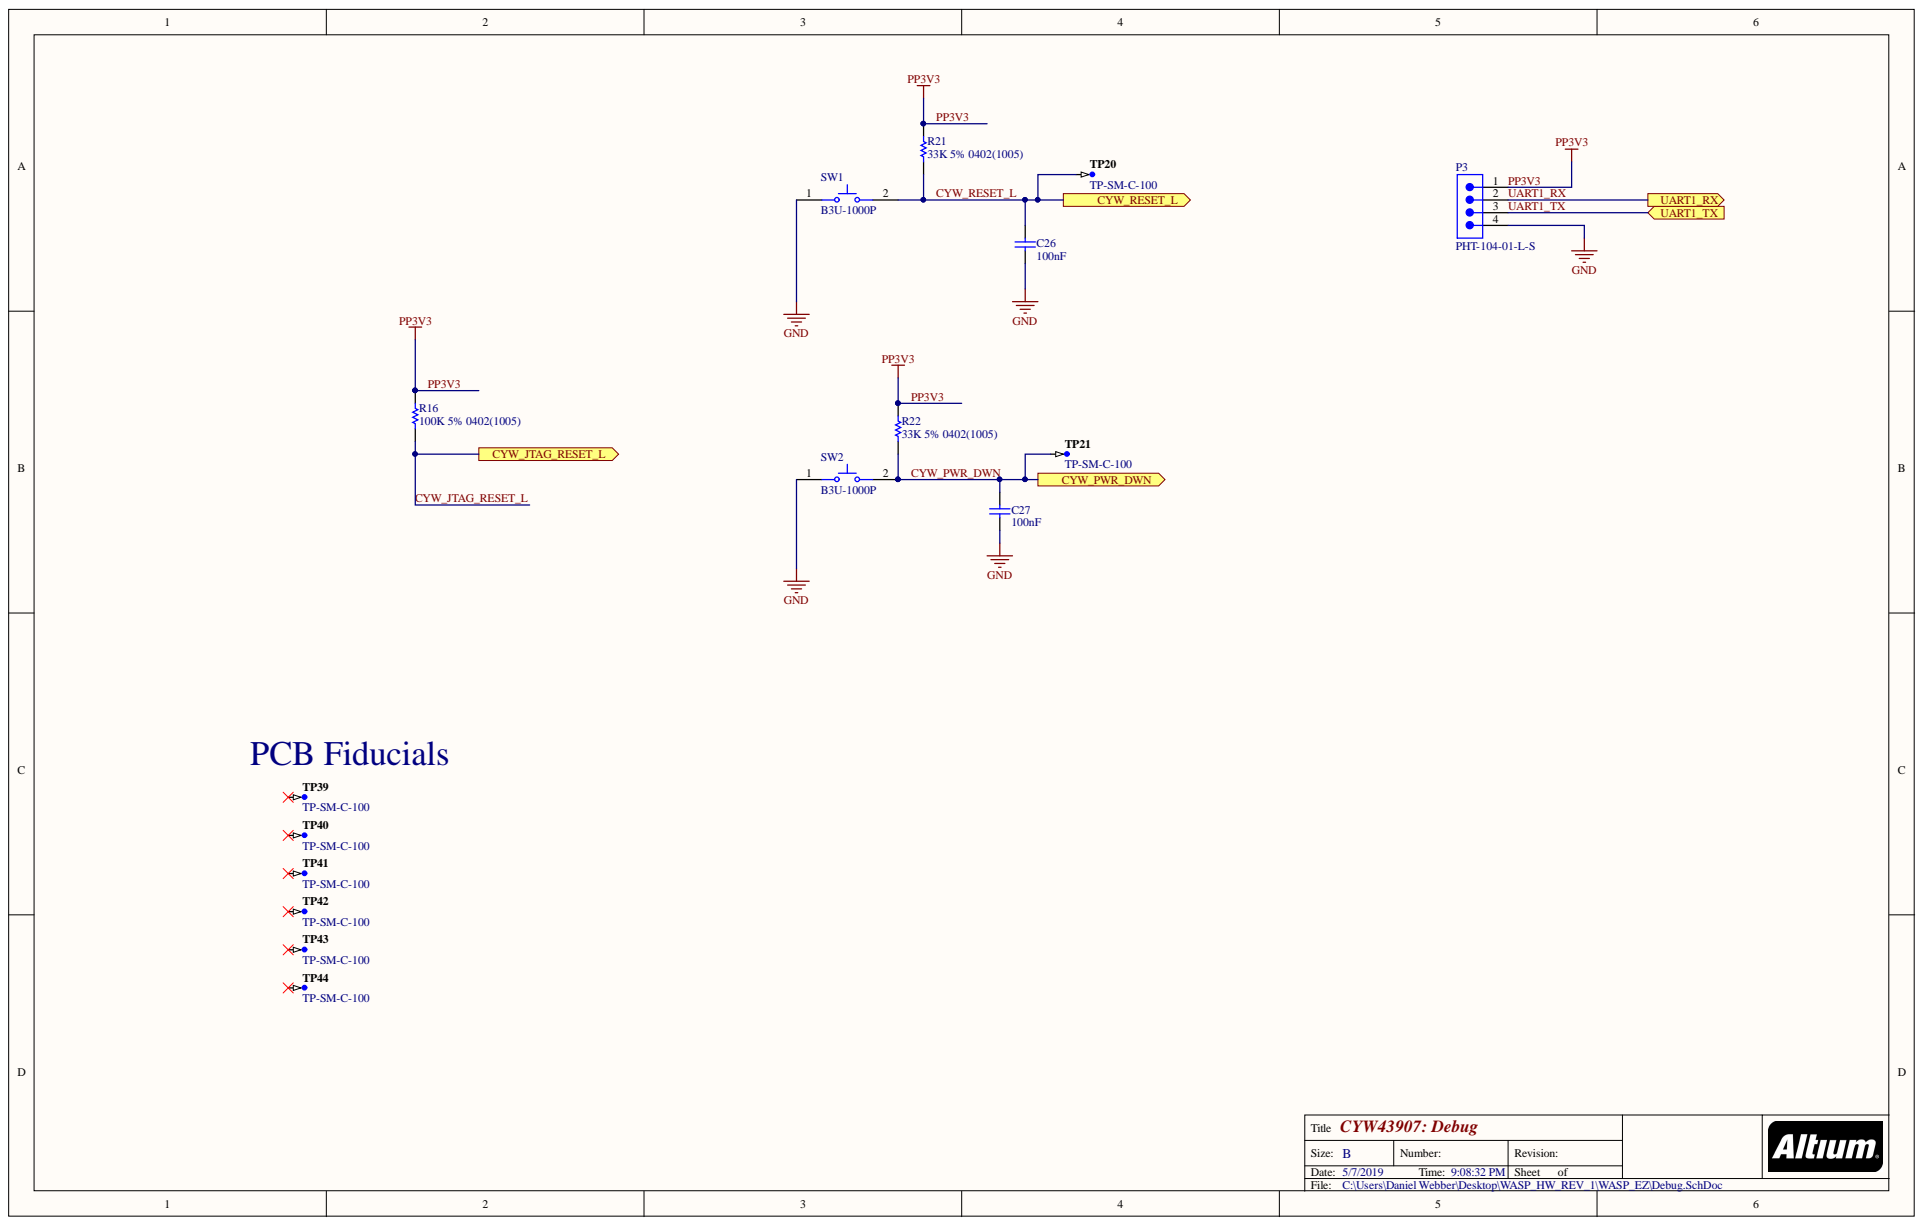
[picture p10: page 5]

Title CYW43907: Debug

Size: B | Number: | Revision:
Date: 5/7/2019 Time: 9:08:32 PM | | Sheet of
File: C:\Users\Daniel Webber\Desktop\WASP_HW_REV_1\WASP_EZ\Debug.SchDoc

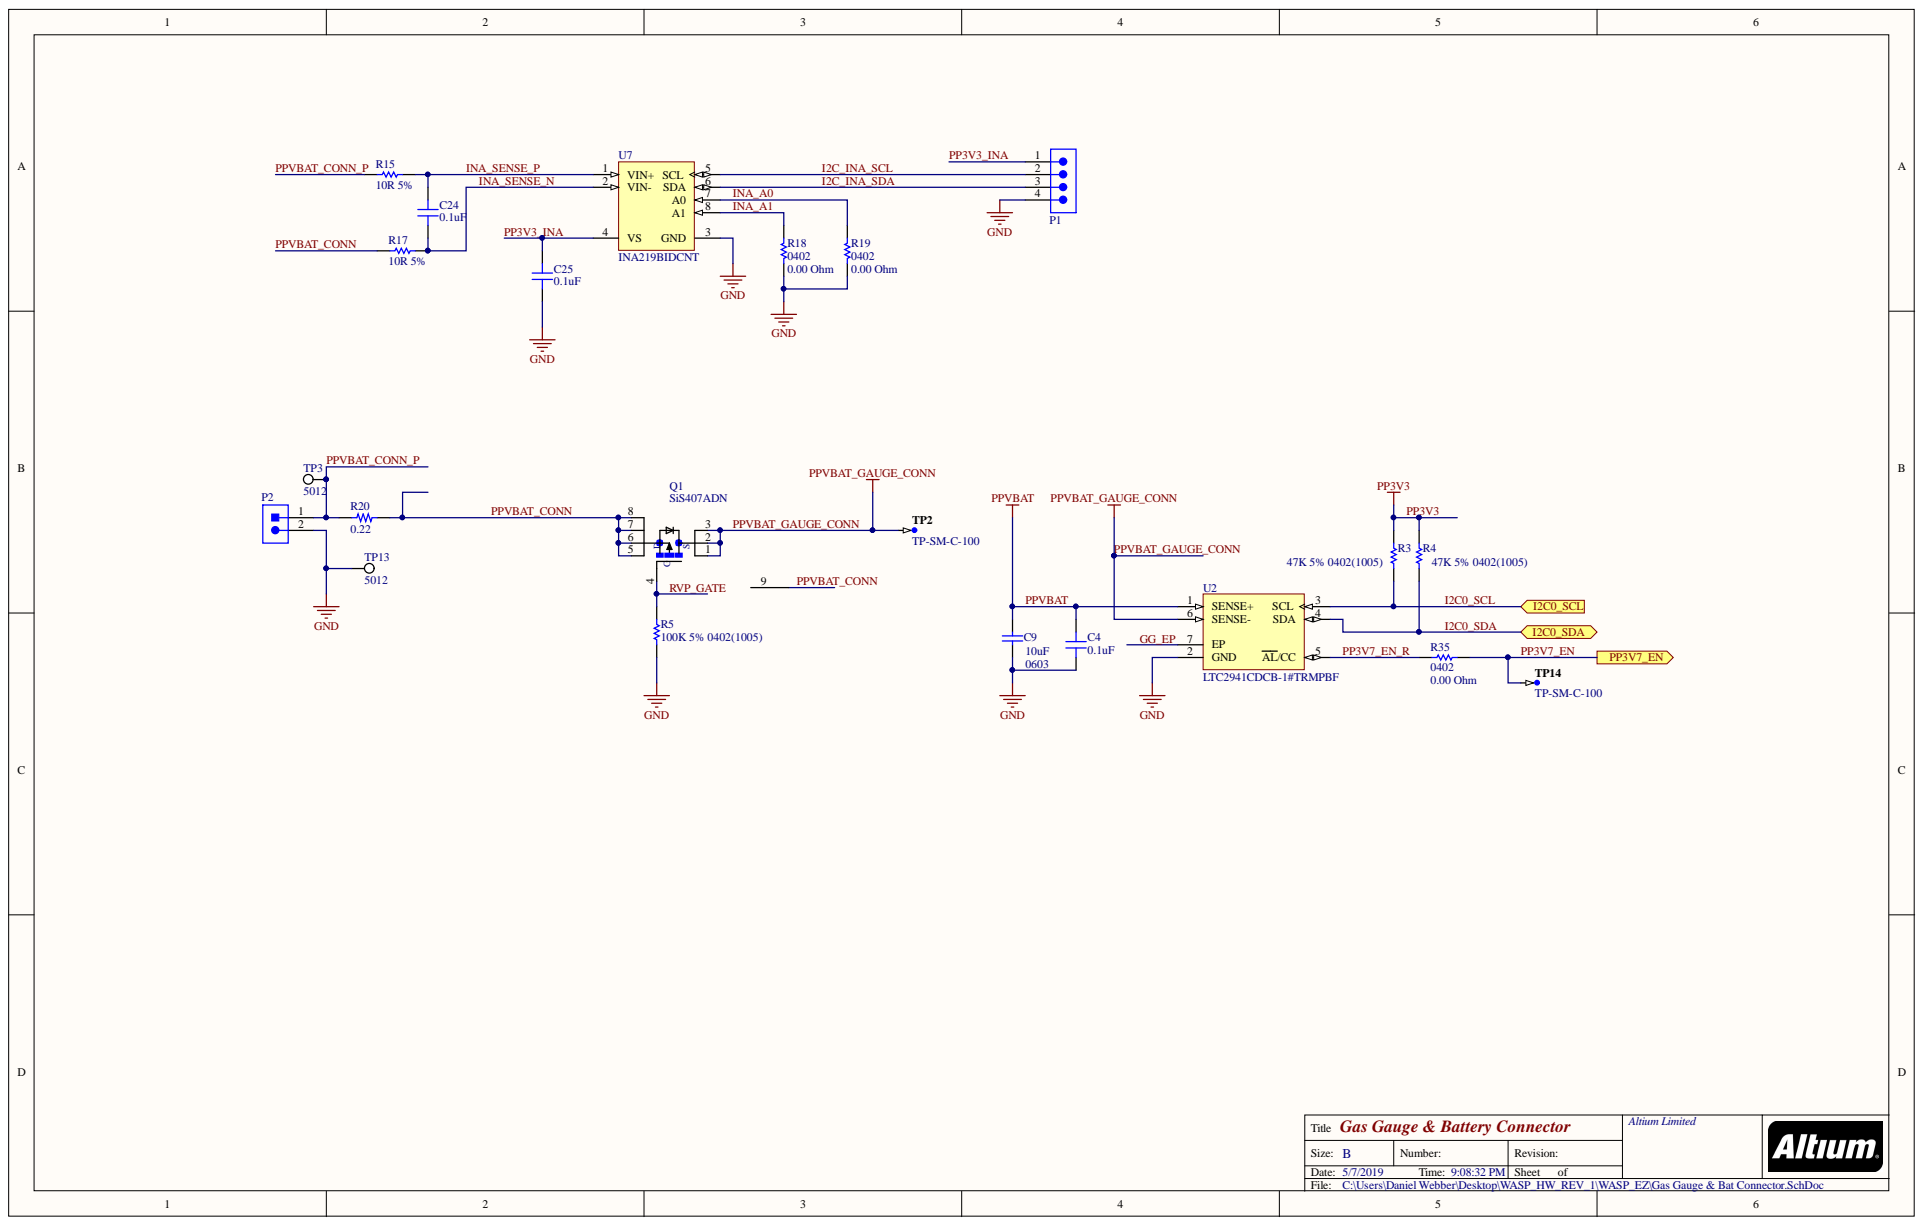
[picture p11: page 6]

PPVBAT_CONN_P

C9 | SENSE- 6 | I2C0_SDA

Title | Altium Limited Gas Gauge & Battery Connector

Size: B | Number: | Revision:
Date: 5/7/2019 Time: 9:08:32 PM | | Sheet of
File: C:\Users\Daniel Webber\Desktop\WASP_HW_REV_1\WASP_EZ\Gas Gauge & Bat Connector.SchDoc

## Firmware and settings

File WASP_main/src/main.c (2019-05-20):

#include "../headers/WASP.h"

void spi_startup(void *arg);
void sample_main(void *arg);

void run_calibration(void *arg);

wiced_queue_t spi_starup_queue;
wiced_thread_t spi_sample_thread;
wiced_thread_t udp_network_thread;


void application_start( )
{
    /*
     * wasp boot sequence elaboration
     * check if its an ota boot
     * if yes - update
     * if no, continue
     *
     * check if we have just returned from hibernate
     * if no -
     *   bring up the gas guage for first boot
     * if yes -
     *   check battery level instead of initializing the gas guage
     *   proceed to rest of boot
     *
     *
     * normal boot
     * init the device
     * bring up the adc and prepare it for taking data
     * bring up network
     * register with server
     *      check to see if we should hibernate again
     *      if yes - go to hibernate
     *      if no - begin to wait
     *
     *
     * going to sleep -
     * set ota mode
     * undo adc status reg?
     * set dct 2.4 ghz?
     */

    int bootflag = is_ota_boot();
    if(bootflag)
    {
        WPRINT_APP_INFO( ( "OTA\n") ); //change this to OTA boot function when ready
        ota_update();
    }

    //no else needed, if not ota just keep on as per usual

    uint16_t prescaler = find_prescalar();
    wiced_result_t result;
    wiced_timer_t timer;
    uint8_t batt_level;
    init_response_t server_init_cmds;
    init_packet_t registration_pckt;
    wiced_mac_t hostmac;
    wiced_result_t res;

    int returned_from_hib = is_hib_wake();
    if(returned_from_hib) //we DID just return from hibernate, which means dont set
    {
        WPRINT_APP_INFO( ( "returned from hib\n") );
        wiced_rtos_delay_milliseconds(100); //do we need to wait for v ails here too?
        //check batt level
        batt_level = battery_percentage(prescaler);
    }
    else //first time boot, bring up gas guage
    {
        WPRINT_APP_INFO( ( "first boot.\n") );
        //delay to let the voltage rails come up
        wiced_rtos_delay_milliseconds(100);
        result = LTC2941_init_startup();
        if(result != WICED_SUCCESS)
        {
            //blink red only - gas gauage didnt come up correctly.
            result = blink(3, 500, &timer); //blink every half second
        }
        batt_level = battery_percentage(prescaler); //should be 100%
    }

    //need to get data back from spi init thread - use a queue
    //we will read the data and immediately deallocate the space.
    result = wiced_rtos_init_queue(&spi_starup_queue, NULL, 4, 1);
    if(result == WICED_SUCCESS)
        WPRINT_APP_INFO( ( "good test code queue\n"));

    //adc stuff - it exists in a different thread
    //ideally we would want this in the same thread, but it needs a bigger stack
    //and we cant seem to give the main thread a bigger stack through wiced_defaults.h

    wiced_thread_t spi_init_thread;
    result = wiced_rtos_create_thread (&spi_init_thread, 0, "", spi_startup, 10*1024, 0);

    wiced_rtos_thread_join(&spi_init_thread); //wait for it to finish
    uint32_t test_codes;
    result = wiced_rtos_pop_from_queue(&spi_starup_queue, &test_codes, 0);

    registration_pckt.test_codes = (uint16_t)test_codes;

    //dealloc the queue - not needed anymore
    wiced_rtos_deinit_queue(&spi_starup_queue);

    //gas guage is finished, do rest of intialization
    wiced_init(); //initialized the RTOS

    //bring up the network using last know config
    wiced_network_up(WICED_STA_INTERFACE, WICED_USE_EXTERNAL_DHCP_SERVER, NULL);


    //create the TCP client to register with the server
    result = tcp_init();
    if(result != WICED_SUCCESS)
        WPRINT_APP_INFO( ( "TCP FAILED\n") );


    //fill the registration packet appropriately.
    hostmac = get_mac();
    memcpy(registration_pckt.mac, hostmac.octet, sizeof(registration_pckt.mac));
    registration_pckt.battery_level = batt_level;
    WPRINT_APP_INFO( ( "batt level = %d\n", batt_level) ); //debug
    registration_pckt.version_major = 1;
    registration_pckt.version_minor = 0;


    float mah = LTC2941_get_mAh(prescaler);
    WPRINT_APP_INFO( ( "mah = %f\n", mah) ); //debug


    //register with server
    server_init_cmds = register_with_server(registration_pckt);

    //check to see if registration was an error
    if(server_init_cmds.port == 0)
    {
        //error, something went wrong
        WPRINT_APP_INFO( ( "ERROR PORT NOT ASSIGNED\n") );
        //maybe send back to hib in this case
        send_to_hibernate();
        return;
    }

    //check whether we got the command to calibrate
    if(server_init_cmds.calibrate == 1)
    {
        WPRINT_APP_INFO( ( "Got calibration command.\n") );
        WPRINT_APP_INFO( ( "Calibration will begin in 30sec.\n") );

        result = blink(1, 500, &timer); //blink the red led until the test starts
        wiced_rtos_delay_milliseconds(30000);
        stop_blink(1, 0, &timer);

        result = blink(3, 500, &timer); //blink both until calibration is done
        WPRINT_APP_INFO( ( "Running calibration test.\n") );
        //calibration involves sampling, need to do another thread

        wiced_thread_t calibration_thread;
        result = wiced_rtos_create_thread (&calibration_thread, 0, "", run_calibration, 10*1024, 0);
        wiced_rtos_thread_join(&calibration_thread); //wait for it to finish
        WPRINT_APP_INFO( ( "Finished calibrating\n") );
        stop_blink(1, 1, &timer);
    }

    //check whether to go back to sleep or not.
    if(server_init_cmds.send_to_hibernate == 1) //for test, should always be 1
    {
        WPRINT_APP_INFO( ( "SERVER SENDING TO HIB\n") );

        //should we disconnnect from tcp? we wont yet but maybe we should.

        //ota boot should still be zero - leave it be.

        //go back to hibernate for another 10 mins.
        send_to_hibernate();
    }

    //if we got past we got at least 1 command
    if(server_init_cmds.fetch_update_command == 1)
    {
        //set the ota params in dct and send to hib to reset

        //for now just going to use the server addr and a const name.
        //TODO - have the server send this in response packet.
        int n = sizeof(SERVER_IP_STRING);
        n += sizeof("/OTA2_image_file.bin");
        n--; //removes an extra null
        char *server = (char*) malloc((n)*sizeof(char));
        strcpy(server, SERVER_IP_STRING);
        strcpy(server, "/OTA2_image_file.bin"); //one these should be a memcpy
        send_to_OTA(server);
    }

    //if we got here, its just commands
    //we didnt get told to go to hib, so get ready to do the test while we can
    //switching networks and extra self tests are unimplemented as of yet

    uint16_t port = server_init_cmds.port;
    WPRINT_APP_INFO( ( "port %d\n", port) );
    platform_init_nanosecond_clock();

    //create udp socket
    init_udp(port);
    WPRINT_APP_INFO( ( "created udp socket at port %d\n", port) );

    //sync with ntp
    WPRINT_APP_INFO( ( "starting time sync..\n") );
    sntp_start_auto_time_sync( TIME_SYNC_PERIOD );
    WPRINT_APP_INFO( ( "finished.\n") );

    //create queues and fill them like normal
    result = init_queues(); //not needed by non perfect function
    WPRINT_APP_INFO( ( "queues ready.\n") );

    //spawn tcp async thread?
    //wiced_thread_t tcp_async_thread; does this need to be a thread??
    //tests say no thread needed
    tcp_server_start_async();

    //wait for the test start broadcast
    WPRINT_APP_INFO( ( "waiting for broadcast\n") );
    result = rx_udp();
    if(result == WICED_SUCCESS)
        WPRINT_APP_INFO( ( "start test\n") );


    //sample and send thread
    wiced_thread_t dummy;
    result = wiced_rtos_create_thread (&dummy, 4, "send_samples", tx_udp_packet_known_good, 10*1024, NULL);
    wiced_rtos_thread_join(&dummy);


    //cant get these to work for the life of me - something is messed up that I cant seem to figure out after weeks
    //result = wiced_rtos_create_thread (&udp_network_thread, 4, "udp", send_wasp_packets, 10*1024, &port);
    //if(result == WICED_SUCCESS)
    //    WPRINT_APP_INFO( ( "udp thread started\n") );
    //else
    //    WPRINT_APP_INFO( ( "udp thread ERROR!\n") );

    //spawn producer thread
    /*
    wiced_thread_t spi_sample_thread;
    result = wiced_rtos_create_thread (&spi_sample_thread, 4, "spi", sample_main, 15*1024, NULL);
    if(result == WICED_SUCCESS)
        WPRINT_APP_INFO( ( "spi thread started\n") );
    else
        WPRINT_APP_INFO( ( "spi thread ERROR!\n") );

    wiced_rtos_thread_join(&spi_sample_thread);
    */

    return;
}

void run_calibration(void *arg)
{
    /*
     * this function (run in its own thread cause it does spi) is responsible
     * for taking 1000 samples and averaging them, as well as sending that average
     * back to the server so it can store that data for post processing.
     */

    //uint16_t samples[1000]; //if we want to do more than this we will need to a running average
                            //we dont want to consume too much stack (wed need to give it more)


    //spi variables
    uint16_t cur_sample = 0;
    int16_t nsegments = 2;
    wiced_spi_message_segment_t message[1];
    uint8_t txbuf[2], rxbuf[2];
    txbuf[0] = 0xFF;
    txbuf[1] = 0xFF;
    message[0].tx_buffer = txbuf;
    message[0].rx_buffer = rxbuf;
    message[0].length = 2;

    float sum = 0;
    float average = 0;

    for(int i = 0; i < 1000; i++)
    {
        wiced_gpio_output_high(WICED_GPIO_34);
        wiced_gpio_output_high(WICED_GPIO_34);
        wiced_gpio_output_low(WICED_GPIO_34);
        if (wiced_spi_transfer(&spi_device , message, nsegments)!=WICED_SUCCESS)
        {
            //will need to retry this sample
            i--;
        }
        cur_sample = ((uint16_t)rxbuf[0] << 8) | rxbuf[1];
        //samples[i] = cur_sample;
        sum += (float)cur_sample;
        WPRINT_APP_INFO( ( "sample = %d, sum = %f\n", cur_sample, sum) );
        wiced_rtos_delay_milliseconds(100); //what should this be
    }

    //got the data, do the average

    average = sum/1000.0;

    WPRINT_APP_INFO( ( "calculated averagae = %f\n", average) );

    //send the average to the server
    //we shouldnt have dissconected, so we should just be able to send the data back

    send_calibration_data(average);

    return;
}


void spi_startup(void *arg)
{
    UNUSED_PARAMETER(arg);

    wiced_result_t res;
    uint32_t testcodes = 0;
    uint8_t one = 1;

    adc_adxl_setup(); //init gpios

    res = adc_unset_high_z();
    if(res == WICED_SUCCESS)
    {
        testcodes |= one;
        WPRINT_APP_INFO( ( "adc reset success\n") );
    }

    res = adxl_self_test();
    if(res == WICED_SUCCESS)
    {
        testcodes |= (one<<1);
        WPRINT_APP_INFO( ( "self test pass\n") );
    }

    res = adc_set_high_z();
    if(res == WICED_SUCCESS)
    {
        testcodes |= (one<<2);
        WPRINT_APP_INFO( ( "set high z success\n") );
    }
    wiced_rtos_push_to_queue(&spi_starup_queue, &testcodes, 0);
    return;
}

void sample_main(void *arg)
{
    UNUSED_PARAMETER(arg);
    uint64_t nano_test_start;
    uint64_t nano_test_end;
    uint64_t nano_time;
    wiced_iso8601_time_t iso8601_time;
    uint16_t sample1;
    uint16_t sample2;
    uint32_t comm_message;
    uint32_t loopcount = 0;
    uint32_t pckt_count = 0;
    uint64_t command;
    uint32_t send = 0;
    wiced_result_t ret;
    wasp_pckt_t raw_data;
    int tx_count = 0;

    //platform_init_nanosecond_clock();

    int16_t nsegments = 2;
    wiced_spi_message_segment_t message[1];
    uint8_t txbuf[2], rxbuf[2];

    //send all ones for  conversion
    txbuf[0] = 0xFF;
    txbuf[1] = 0xFF;
    message[0].tx_buffer = txbuf;
    message[0].rx_buffer = rxbuf;
    message[0].length = 2;
    WPRINT_APP_INFO( ( "begin sampling\n") );

    nano_test_start = wiced_get_nanosecond_clock_value(); //mark it just in case, nut test ends will be async
    while(!test_concluded)
    {
        //this isnt EXACTLY regular - TODO.
        wiced_time_get_iso8601_time( &iso8601_time );
        nano_time = wiced_get_nanosecond_clock_value();
        //wiced_rtos_push_to_queue(&iso_time_queue, &iso8601_time, 0);
        //wiced_rtos_push_to_queue(&nano_time_queue, &nano_time, 0);

        raw_data.packet_count = tx_count++;
        raw_data.time_start = iso8601_time;
        raw_data.nano_time_start = nano_time;

        for(int i = 0; i < 118; i++)
        {
            wiced_gpio_output_high(WICED_GPIO_34);
            wiced_gpio_output_high(WICED_GPIO_34);
            wiced_gpio_output_low(WICED_GPIO_34);
            wiced_spi_transfer(&spi_device , message, nsegments);
            sample1 = ((uint16_t)rxbuf[0] << 8) | rxbuf[1];

            wiced_gpio_output_high(WICED_GPIO_34);
            wiced_gpio_output_high(WICED_GPIO_34);
            wiced_gpio_output_low(WICED_GPIO_34);
            wiced_spi_transfer(&spi_device , message, nsegments);
            sample2 = ((uint16_t)rxbuf[0] << 8) | rxbuf[1];


            //comm_message = ((uint32_t)sample1 << 16) | sample2;
            //wiced_rtos_push_to_queue(&main_queue, &comm_message, 0);

            raw_data.samples[i] = sample1;
            raw_data.samples[i+1] = sample2;
        }

        //create message for the other thread
        loopcount++;
        if(loopcount >= 3)
        {
            pckt_count++;
            send = 1;
        }

        //command = ((uint64_t)pckt_count << 32) | send;
        //wiced_rtos_push_to_queue(&comm_queue, &command, 0);

        //wiced_watchdog_kick(); //need to kick watchdog to avoid a reset, see documentation for this function

        //test only, this should be deleted
        tx_udp_packet();
        //tx_udp_packet_arg(&raw_data);
    }

    nano_test_end = wiced_get_nanosecond_clock_value();
    //compute delta if needed

    //wait for other thread to be done, then go to hib.
    //wiced_rtos_thread_join(&udp_network_thread);
    send_to_hibernate();


    return;
}

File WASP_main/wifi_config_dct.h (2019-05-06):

#pragma once

#ifdef __cplusplus
extern "C"
{
#endif

/**
 * This is the soft AP used for device configuration
 */
#define CONFIG_AP_SSID       "WICED Config"
#define CONFIG_AP_CHANNEL    1
#define CONFIG_AP_SECURITY   WICED_SECURITY_WPA2_AES_PSK
#define CONFIG_AP_PASSPHRASE "12345678"

/**
 * This is the soft AP available for normal operation (if used)
 */
#define SOFT_AP_SSID         "WICED Device"
#define SOFT_AP_CHANNEL      1
#define SOFT_AP_SECURITY     WICED_SECURITY_WPA2_AES_PSK
#define SOFT_AP_PASSPHRASE   "WICED_PASSPHRASE"


/**
 * This is the default AP the device will connect to (as a client)
 */

#define CLIENT_AP_SSID              "apt1308"
#define CLIENT_AP_PASSPHRASE        "DDTC2019!"
#define CLIENT_AP_BSS_TYPE          WICED_BSS_TYPE_INFRASTRUCTURE
#define CLIENT_AP_SECURITY          WICED_SECURITY_WPA2_MIXED_PSK
#define CLIENT_AP_CHANNEL           1
#define CLIENT_AP_BAND              WICED_802_11_BAND_2_4GHZ

/*
#define CLIENT_AP_SSID              "WASP_2.4"
#define CLIENT_AP_PASSPHRASE        "BbBR977KrhAnG33Q"
#define CLIENT_AP_BSS_TYPE          WICED_BSS_TYPE_INFRASTRUCTURE
#define CLIENT_AP_SECURITY          WICED_SECURITY_WPA2_MIXED_PSK
#define CLIENT_AP_CHANNEL           1
#define CLIENT_AP_BAND              WICED_802_11_BAND_2_4GHZ
*/

#define CLIENT_AP_2_SSID            "WASP_5.0"
#define CLIENT_AP_2_PASSPHRASE      "GSf2dSaqJYFf9Akc"
#define CLIENT_AP_2_BSS_TYPE        WICED_BSS_TYPE_INFRASTRUCTURE
#define CLIENT_AP_2_SECURITY        WICED_SECURITY_WPA2_MIXED_PSK
#define CLIENT_AP_2_CHANNEL         1
#define CLIENT_AP_2_BAND            WICED_802_11_BAND_5GHZ

#define CLIENT_AP_3_SSID            "OpenWrtX"
#define CLIENT_AP_3_PASSPHRASE      "seniordesign2019"
#define CLIENT_AP_3_BSS_TYPE        WICED_BSS_TYPE_INFRASTRUCTURE
#define CLIENT_AP_3_SECURITY        WICED_SECURITY_WPA2_MIXED_PSK
#define CLIENT_AP_3_CHANNEL         1
#define CLIENT_AP_3_BAND            WICED_802_11_BAND_2_4GHZ


/**
 * The network interface the device will work with
 */
#define WICED_NETWORK_INTERFACE   WICED_STA_INTERFACE

#ifdef __cplusplus
} /*extern "C" */
#endif

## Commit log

2019-05-04 initial code push, adxl driver just finished
2019-05-06 updating main.c
    [BCM4390x.cfg]
2019-05-08 WASP REV 1 Design
    Commiting WASP REV 1.
    This contains all of the needed libraries to work with the WASP design.
    [ADC - AD4008.SchDoc, Accelerometer -ADXL1004.SchDoc, Buck Boost.SchDoc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]
2019-05-12 Create WASP_EZ_BOM1_QUOTE.xls
    Adding up to date BOM. Note R27 now NO STUFF and R28 not no stuff. This is done to reflect the correct strapping for the 1V8 LDO.
    [WASP_EZ_BOM1_QUOTE.xls]
2019-05-12 Quicksilver Info
    Adding the daughter board (quicksilver EZ). These files were given to sierra to provide guidence on how to assemble this portion of our board.
    [WASP_EZ_BOM1_QUOTE.xls]
2019-05-13 Working demo push. changes to client and server, addition of proto mfg dct images for easy MAC association to boards
2019-05-13 Adding Quicksilver-EZ breakout board
    This board was a test board that we designed to verify the pinout and programming scheme of the Arrow module.
    [CYW43907_BO.SchDoc, WASP_BO_DEBUG.SchDoc, WASP_BO_PCB.PcbDoc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]
2019-05-19 added power testing, board calib, server cli, in the process of editing server to support the new calibration tests
2019-05-20 move fast_ina to power test
2019-05-20 moved to power test folder
2019-05-20 calibration completed, added proto-sdp implementation
2019-05-21 added calibration to post processing - also did a quick speed optimization
2019-05-22 Create WASP_MECH_DRAWING_040819.pdf
    Adding more indepth mech drawing. This includes part call outs that are used for assembly, note only parts that are included in the BOM are shown
2019-05-27 added color print to self test status
2019-05-28 fixed minor format problem from the color print
2019-05-29 dir cleanup
    [BCM4390x.cfg]
